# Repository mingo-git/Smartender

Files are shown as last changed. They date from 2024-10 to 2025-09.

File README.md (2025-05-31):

# Smartender

## Deployment

### 1. Image bauen

```bash
docker build -t gcr.io/gothic-sequence-443115-v5/smartender:latest .
```

### 2. Image pushen

```bash
docker push gcr.io/gothic-sequence-443115-v5/smartender:latest
```

### 3. Befehl um das neuste Image zu deployen

```bash
gcloud run services update smartender --image gcr.io/gothic-sequence-443115-v5/smartender:latest --region europe-west3
```

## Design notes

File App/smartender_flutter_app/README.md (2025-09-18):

# smartender_flutter_app

Smartender = Smart Bartender - Flutter

## Getting Started

This project is a starting point for a Flutter application.

A few resources to get you started if this is your first Flutter project:

- [Lab: Write your first Flutter app](https://docs.flutter.dev/get-started/codelab)
- [Cookbook: Useful Flutter samples](https://docs.flutter.dev/cookbook)

For help getting started with Flutter development, view the
[online documentation](https://docs.flutter.dev/), which offers tutorials,
samples, guidance on mobile development, and a full API reference.

In die .env ->
GOOGLE_WEB_CLIENT_ID=*Generate your own Client-ID*
BASE_URL=*Use for Development your ip (Windows -> "ipconfig")*
API_KEY=*???*

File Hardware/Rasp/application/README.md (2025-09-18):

# Suggested File structure according to ChadGPT

```plainText
iot_project/
│
├── main.py                    # Einstiegspunkt der Anwendung
├── config.py                  # Konfigurationsdateien und Parameter
├── modules/                   # Modulverzeichnis
│   ├── websocket_handler.py   # Websocket-Logik
│   ├── motor_controller.py    # Steuerung des Servo- und Linearmotors
│   ├── pump_controller.py     # Pumpensteuerung
│   ├── position_handler.py    # Logik für Endschalter und Positionshandling
│   ├── weight_sensor.py       # Waagenanbindung
│   ├── led_controller.py      # Steuerung des LED-Streifens
│   ├── command_mapper.py      # Befehlsmapper für Websocket-Befehle
│   ├── error_handler.py       # Fehlerbehandlung und Rückmeldungen
│   └── utils/                 # Hilfsfunktionen und Utility-Skripte
│       └── logger.py          # Logging
│
└── tests/                     # Unittests
    ├── test_websocket.py
    ├── test_motors.py
    ├── test_pumps.py
    └── ...
```

## TODOs

- [ ] main.py anlegen und füllen
- [ ] Websocket Klasse implementieren
- [ ] Websocket automatischer reconnect wenn Verbindung unterbrochen wird
- [ ] MotorController Klasse anlegen
- [ ] PumpController Klasse anlegen
- [ ] PositionHandler Klasse anlegen
- [ ] WeightSensor Klasse anlegen
- [ ] LEDController Klasse anlegen
- [x] CommandMapper Klasse anlegen
- [ ] ErrorHandler Klasse anlegen
- [x] Logger Klasse anlegen
- [ ] BashScript für schnelle Installation aller Python Packages

## Pins

| PINS | INFO | USAGE | PINS | INFO | USAGE |
| --- | --- | --- | --- | --- | --- |
| Pin 1  | 3.3 V | | Pin 2  | 5 V | |
| Pin 3  | GPIO 2 | | Pin 3  | 5 V | |
| Pin 5  | GPIO 3 | | Pin 6  | Ground | Ground for Raspberry Pi |
| Pin 7  | GPIO 4 | Limit Switch 1 C | Pin 8  | GPIO 14 | LCD SDA |
| Pin 9  | Ground | | Pin 10 | GPIO 15 | LCD SCL |
| Pin 11 | GPIO 17 | Limit Switch 2 C | Pin 12 | GPIO 18 (PWM) | LED LV1 |
| Pin 13 | GPIO 27 | Limit Switch 3 C | Pin 14 | Ground | Shared Ground |
| Pin 15 | GPIO 22 | Limit Switch 4 C | Pin 16 | GPIO 23 | |
| Pin 17 | 3.3 V | | Pin 18 | GPIO 24 | |
| Pin 19 | GPIO 10 | Limit Switch 5 C | Pin 20 | Ground | |
| Pin 21 | GPIO 9 | Limit Switch 6 C | Pin 22 | GPIO 25 | Linear Actuator IN1 |
| Pin 23 | GPIO 11 | Limit Switch 7 C | Pin 24 | GPIO 8 | Linear Actuator IN2 |
| Pin 25 | Ground | | Pin 26 | GPIO 7 | Linear Actuator IN3 |
| Pin 27 | GPIO 0 | Pump 1 | Pin 28 | GPIO 1 | Linear Actuator IN4 |
| Pin 29 | GPIO 5 | Pump 2 | Pin 30 | Ground | |
| Pin 31 | GPIO 6 | Pump 3 | Pin 32 | GPIO 12 (PWM) | Stepper DA |
| Pin 33 | GPIO 13 (PWM) | Pump 4 | Pin 34 | Ground | Ground Stepper |
| Pin 35 | GPIO 19 (PWM) | Pump 5 | Pin 36 | GPIO 16 | Stepper Dir |
| Pin 37 | GPIO 26 | Pump 6 | Pin 38 | GPIO 20 | Scale DT |
| Pin 39 | Ground | | Pin 40 | GPIO 21 | Scale SCK |

## Liste der nötigen Python-Imports

- `sudo apt install python3-websocket`
- `sudo apt install python3-rx`
- `sudo apt-get install python3-pip`
- `pip install --break-system-packages 'git+https://github.com/gandalf15/HX711.git#egg=HX711&subdirectory=HX711_Python3'`

- `sudo pip3 install XYZ --break-system-packages`

## Pi neu aufsetzen

- sudo apt install git
- ssh-keygen -t ed25519 -C "your_email@example.com"
- git config --global user.email "you@example.com"
- git config --global user.name "Your Name"

- sudo apt install vim
- python3 -m venv ~/myenv
- source ~/myenv/bin/activate
- pip install websocket-client
- pip install rx
- sudo apt update
- sudo apt install python3-dev
- sudo apt install build-essential
- pip install RPi.GPIO
- pip install pigpio
- sudo systemctl enable pigpiod
- sudo systemctl start pigpiod
- pip install hx711
- pip install rpi_ws281x
- pip install python-dotenv
-

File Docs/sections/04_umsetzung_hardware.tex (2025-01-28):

\subsection{Überblick}
Die Hardwareplattform für das Projekt bildet das Herzstück des Cocktailautomaten und wurde mit dem 
Ziel ausgewählt, eine robuste und flexible Steuerung der mechanischen und elektronischen 
Komponenten zu gewährleisten. Die Wahl fiel auf den \textbf{Raspberry Pi Zero 2 W}, eine kompakte 
und leistungsfähige Single-Board-Computer-Lösung, die sich aufgrund ihrer Vielseitigkeit und der 
umfangreichen Unterstützung von Python-Bibliotheken ideal für IoT-Anwendungen eignet. Ergänzt wird 
der Raspberry Pi durch eine Vielzahl von Sensoren, Aktoren und Peripheriegeräten, die zusammen die 
präzise Steuerung des Automaten ermöglichen.

\subsection{Zentrale Steuerung}
\hyphenation{Blue-tooth-Kon-nek-ti-vi-tät}
\hyphenation{WLAN-Kon-fi-gu-ra-tion}
% TODO: fix hyphenation for 'Bluetooth-Konnektivität'
Der Raspberry Pi Zero 2 W übernimmt die zentrale Steuerung des Systems. Mit einem Quad-Core ARM 
Cortex-A53-Prozessor und integrierter WLAN- und Bluetooth-Konnektivität \cite{raspberrypi} eignet 
sich der Pi optimal für die Verarbeitung der Steuerungslogik und die Kommunikation mit dem Backend.

\subsection{Mechanische Komponenten}
\subsubsection{Schrittmotor für die Positionierung}
Ein Schrittmotor steuert die präzise Bewegung eines Förderbandsystems, welches die verschiedenen 
Getränkezutaten anfahren kann. Mit einem Dir- und Pul-Pin-Design wird der Schrittmotor über einen 
\textbf{Treiber} angesteuert, der eine feine Steuerung der Bewegung und Geschwindigkeit ermöglicht. 
Ein Schlitten bewegt sich zwischen den Slots, die durch Endschalter (Limit Switches) abgegrenzt 
sind.

\subsubsection{Linearantrieb für alkoholische Getränke}
Ein Linearmotor aktiviert die Dosiermechanismen für alkoholische Zutaten, die kopfüber montiert 
sind. Der Antrieb hebt die Dosiermechanik an, um Flüssigkeiten aus den Flaschen freizugeben, und 
stellt sicher, dass die gewünschte Menge präzise abgefüllt wird.

\subsubsection{Membranpumpen für nicht-alkoholische Zutaten}
Sechs Membranpumpen sind für die Abgabe von nicht-alkoholischen Zutaten zuständig. Diese Pumpen 
ermöglichen eine genaue Dosierung der Flüssigkeiten und werden einzeln über GPIO-Pins des 
Raspberry Pi angesteuert. Jede Pumpe ist einem festen Slot zugewiesen.

\subsection{Sensorik}
\subsubsection{Endschalter für die Positionserkennung}
Sechs Endschalter (Limit Switches) überwachen die genaue Position des Schlittenmechanismus. 
Endschalter 0 ist für die Kalibrierung vorgesehen und dient als Referenzpunkt. Außerdem werden an 
diesem Punkt die nicht-alkoholischen Getränke am Ende der Zubereitung zugefügt. Die übrigen 
Schalter (1--5) bilden die Position der Slots für alkoholische Getränke (ebenfalls 1--5) ab.

\subsubsection{Waage für Gewichtsmessung}
Eine elektronische Waage auf Basis eines HX711-Sensors misst das Gewicht der Getränke während der 
Zubereitung. Sie dient nicht nur der Überwachung der genauen Flüssigkeitsmengen, sondern auch der 
Erkennung, ob eine Zutat aufgebraucht ist.

\subsection{Stromversorgung}
Die gesamte Hardware wird von einem \textbf{24V-Netzteil} mit ausreichender Leistung (mindestens 3A
) versorgt. Zwei \textbf{Step-Down-Spannungsregler} wandeln die Spannung auf 5V respektive 12V für 
den Raspberry Pi und weitere elektronische Komponenten um. Zur Vermeidung von 
Spannungsschwankungen und elektromagnetischen Störungen wurden \textbf{Kondensatoren} integriert, 
die die Stabilität der Stromversorgung sicherstellen.

\subsection{Zusammenarbeit der Komponenten}
Alle Hardwarekomponenten arbeiten nahtlos zusammen, um die Zubereitung eines Cocktails zu 
automatisieren:
\begin{itemize}
    \item Die \textbf{Positionserkennung} sorgt dafür, dass der Schlitten immer die korrekte 
        Position ansteuert.
    \item Die \textbf{Waage} und die Pumpen oder der Linearantrieb arbeiten zusammen, um die 
        exakte Menge jeder Zutat abzugeben.
\end{itemize}

\subsection{Pinbelegung und Schaltplan}
Die genaue Pinbelegung \ref{fig:pinning} sowie der vollständige Schaltplan \ref{fig:schaltplan} 
der Hardware sind im Anhang zu finden. Das Pinning-Sheet dokumentiert die Zuordnung der GPIO-Pins 
des Raspberry Pi zu den verschiedenen Komponenten wie Schrittmotor, Linearantrieb, Pumpen, 
Endschaltern und Waage. Der Schaltplan bietet einen Überblick über die elektrische Verkabelung und 
die Integration der Stromversorgung sowie der Steuereinheiten. Beide Dokumente sind essenziell für 
den Nachbau oder die Wartung des Systems.

\subsection{Integration und Herausforderungen}
% TODO: fix hyphenation to fix overfull hbox in 'Stromversorgung'
Die Integration der verschiedenen Hardwarekomponenten erforderte eine sorgfältige Planung, 
insbesondere bei der Belegung der GPIO-Pins und der Kalibrierung der Sensoren. Eine besondere 
Herausforderung stellte die Stabilität der Stromversorgung dar, insbesondere bei Spitzenlasten 
durch den Schrittmotor oder die Pumpen. Durch die Verwendung eines ausreichend dimensionierten 
Netzteils und der Optimierung des Codes konnte dieses Problem erfolgreich gelöst werden.

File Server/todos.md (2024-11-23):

Todos for Server/Database

- [] Endpunkt: Getärnk zubereiten
- [] SQL Query für Rezeptzubereitung (Slots, welcher SLot wie viel usw.)
- [] Datenbankschema migrieren (User, Google Token usw.)
- [] Endpoint Hardware registrieren (User ID)
- [] Mapping Rezepte Backend mit SQL Statement
- [] Rezept über Socket an Pi

- Testing! (Ob Rezepte auf Pi ankommen)

Todos for Pi

- [] Eigenes Wlan aufbauen für Ersteinrichtung
- [] Ersteinrichtung (HW im Backend registrieren etc.)
- [] Datenbankrezepte mappen auf "Arduino Befehle"
- [] Verbindung zu Arduino über I2C/UART (nochmal informieren)
- [] "Arduino Befehle" definieren

- Testing! (Ob Befehle bei Arduino ankommen)

Todos for Arduino

- [] Errorcodes für Fehlerfälle
- [] Daten von Pi auslesen/casten
- [] Großes Switch Statement
- [] Funktionen für Move/Pump/Push
- [] Pins ansteuern

- Testing! (Mit LEDs, einzelne Ports ansprechen)

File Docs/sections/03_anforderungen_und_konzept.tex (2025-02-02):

% Hier folgt der Inhalt des Abschnitts "Anforderungen und Konzept".
Im Rahmen des Projekts „Smarter Cocktailautomat“ wurden grundlegende Anforderungen definiert, die 
sich aus den Zielsetzungen und den zu erwartenden Einsatzszenarien ableiten lassen. Dieser 
Abschnitt gliedert sich in eine Analyse der funktionalen und nicht-funktionalen Anforderungen 
sowie die Entwicklung eines konzeptionellen Architekturansatzes, der die Interaktionen zwischen 
Hardware, Backend und mobiler App beschreibt.

\subsection{Anforderungsanalyse}

Die Anforderungsanalyse bildet die Grundlage für die Entwicklung des Prototyps. Dabei werden 
sowohl funktionale als auch nicht-funktionale Anforderungen betrachtet.

\subsection{Funktionale Anforderungen}

Funktionale Anforderungen beschreiben die Kernfunktionen, die das System erfüllen muss, um die 
Projektziele zu erreichen:

\begin{itemize}
	  \item \textbf{Benutzerregistrierung:} Möglichkeit, Benutzerkonten anzulegen.
	  \item \textbf{Rezeptverwaltung:} Hinzufügen, Bearbeiten und Löschen von Cocktailrezepten über die mobile App.
	  \item \textbf{Zutatenverwaltung:} Verwaltung der im Automaten verfügbaren Zutaten.
	  \item \textbf{Automatisierte Zubereitung:} Präzise Dosierung und Mischung der ausgewählten Zutaten basierend auf den Rezepten.
	  \item \textbf{App-Steuerung:} Steuerung des Cocktailautomaten über eine intuitive Benutzeroberfläche der mobilen App.
	  \item \textbf{Synchronisation mit der Cloud:} Speicherung und Abruf von Benutzerdaten, Rezepten und Maschinenkonfigurationen über ein cloudbasiertes Backend.
\end{itemize}

\subsection{Nicht-funktionale Anforderungen}

Neben den funktionalen Aspekten spielen auch nicht-funktionale Anforderungen eine zentrale Rolle, 
um die Qualität und Benutzerfreundlichkeit des Systems sicherzustellen:

\begin{itemize}
	  \item	\textbf{Skalierbarkeit:} Das System muss in der Lage sein, mehrere Benutzer zu unterstützen, ohne Leistungseinbußen zu erleiden.
	  \item	\textbf{Sicherheitsaspekte:} Schutz von Benutzerdaten durch verschlüsselte Kommunikation und sichere Authentifizierungsverfahren.
	  \item	\textbf{Benutzerfreundlichkeit:} Intuitive Bedienung der mobilen App sowie einfache Wartung und Erweiterung der Hardware.
	  \item	\textbf{Fehlerresistenz:} Robustheit des Systems gegenüber Hardware- und Softwarefehlern.
	  \item	\textbf{Performance:} Minimierung von Latenzen bei der Kommunikation zwischen App, Backend und Hardware.
\end{itemize}

\subsection{Konzeptionelle Architektur}

Auf Basis der definierten Anforderungen wurde eine konzeptionelle Architektur entwickelt, die das 
Gesamtsystem in seinen zentralen Komponenten beschreibt.

Gesamtsystem-Übersicht

Das System besteht aus drei Kernkomponenten:

\begin{enumerate}
  \item \textbf{Hardware:} Der Cocktailautomat als physisches Gerät übernimmt die Dosierung und Mischung der Zutaten.
  \item \textbf{Backend:} Ein containerisiertes Backend, das in Google Cloud Run gehostet wird, dient als zentrale Schnittstelle für die Speicherung und Verarbeitung von Daten.
  \item \textbf{Mobile App:} Eine Smartphone-App ermöglicht die Benutzerinteraktion mit dem System und bietet Funktionen wie Rezeptverwaltung und Steuerung des Automaten.
\end{enumerate}

Die Interaktionen zwischen diesen Komponenten sind in Abbildung \ref{fig:system_overview} 
dargestellt. Dabei wird insbesondere der Datenfluss zwischen den Modulen hervorgehoben.

\vspace{0.5 cm}
\begin{figure}[htbp]
  \centering
	\begin{tikzpicture}[
		>=stealth,   					% Standardpfeilspitzen
		outer sep=6pt,				% Abstand zwischen Text und Rahmen
		inner sep=5pt,				% Abstand zwischen Text und Rahmen
		node distance=6cm,	% Abstand zwischen den Knoten
		font=\sffamily				% Verwendete Schriftart
	]
	
	% Knoten
	\node[draw, rectangle, rounded corners, fill=red3, minimum width=2.5cm, minimum height=1.2cm] (hardware) {Hardware};
	\node[draw, rectangle, rounded corners, fill=red3, minimum width=2.5cm, minimum height=1.2cm, left of=hardware] (backend) {Backend};
	\node[draw, rectangle, rounded corners, fill=red3, minimum width=2.5cm, minimum height=1.2cm, left of=backend] (app) {Mobile App};
	
	% Pfeil 1: ein Wort pro Zeile, zentriert
	\draw[<-, thick] 
	(hardware) 
	-- node[below]{
		\parbox{2.7cm}{\centering
			Rezeptdaten,\\
			Slotbestückung 
		}
	} 
	(backend);

	% Pfeil 2: ein Wort pro Zeile, zentriert
	\draw[<->, thick] 
	(app) 
	-- node[below]{
		\parbox{2.7cm}{\centering
			Benutzerdaten,\\
			Rezepte \&\\
			Konfiguration
		}
	} 
	(backend);

	\end{tikzpicture}

	\caption{Systemübersicht: Interaktionen zwischen Hardware, Backend und mobiler App}
	\label{fig:system_overview}
\end{figure}

\paragraph*{Datenflüsse und Interaktionen}

\begin{itemize}
  \item Die Hardware kommuniziert mit dem Backend, um die aktuellen Maschinenzustände zu synchronisieren.
  \item Die mobile App greift auf das Backend zu, um Benutzerdaten, Rezepte und Maschinenkonfigurationen zu laden und zu speichern.
  \item Das Backend dient als zentrale Vermittlungsstelle und verarbeitet sowohl Steuerbefehle von der App als auch Statusmeldungen der Hardware.
\end{itemize}

\subsection{Schwerpunktsetzung}

Im Rahmen des Projekts wurde besonderes Augenmerk auf die folgenden Aspekte gelegt:

\begin{itemize}
  \item \textbf{Hardware:} Die Hardwareentwicklung zielte auf eine modulare und erweiterbare Bauweise ab, um zukünftige Anpassungen und Erweiterungen zu ermöglichen.
  \item \textbf{Backend:} Aufgrund der hohen Anforderungen an Skalierbarkeit und Sicherheit wurde das Backend so konzipiert, dass es sowohl eine zuverlässige Kommunikation zwischen den Komponenten als auch eine effiziente Datenverwaltung ermöglicht.
  \item \textbf{Mobile App:} Der Fokus lag auf einer benutzerfreundlichen und intuitiven Bedienung, um die Nutzung auch für technisch unerfahrene Anwender zu vereinfachen.
\end{itemize}

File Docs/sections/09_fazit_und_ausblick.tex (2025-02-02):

% Hier folgt der Inhalt des Abschnitts "Fazit und Ausblick".
\subsection{Fazit}
Das Projekt hat gezeigt, dass die Kombination aus Hardware, Software und Cloud-Diensten 
erfolgreich zur Automatisierung der Cocktailzubereitung genutzt werden kann. Die definierten 
Hauptziele des Projekts wurden weitestgehend erreicht:

\begin{itemize}
    \item Die Maschine kann Cocktails entsprechend der über die App ausgewählten Rezepte 
        zusammenmixen.
    \item In der App können Benutzer Getränke, Zutaten und Slots anlegen, ändern und löschen.
    \item Die Integration zwischen App, Backend und Hardware funktioniert stabil und erfüllt die 
        Kernanforderungen.
\end{itemize}

Besonders positiv hervorzuheben ist die erfolgreiche Umsetzung folgender Punkte:

\begin{itemize}
    \item Hosting des Backends über Google Cloud
    \item Erstellung einer funktionsfähigen Android-App
    \item Zuverlässige Verkabelung und Integration der Hardware
\end{itemize}
Trotz der Erfolge gab es auch Herausforderungen, die nur teilweise gelöst werden konnten. 
Beispielsweise verursachen die Treiber des Schrittmotors und des Linearmotors Schwankungen im 
Ground, was die Übertragung von Daten beeinträchtigt. Dies führt insbesondere bei feineren 
Komponenten wie der Waage zu Störungen, obwohl diese außerhalb des Systems problemlos funktioniert 
hat.

Zudem gab es Einschränkungen bei der Auswahl bestimmter Hardware-Komponenten. So sind die 
Spirituosenausschänker gelegentlich unzuverlässig, was zu Ausfällen führen kann. Die Kraft, die 
erforderlich ist, um diese Ausschänker zu bedienen, wurde ebenfalls unterschätzt. Dies machte 
einen Wechsel von Servomotoren zu einem leistungsfähigeren Linearmotor notwendig.

Insgesamt hat das Projekt die Kenntnisse im Bereich Elektronik, Stromversorgung sowie in der 
Entwicklung und Bereitstellung von Apps und Backends erheblich erweitert.

\subsection{Ausblick}
Für die Zukunft sind mehrere Erweiterungen und Optimierungen geplant, um die Funktionalität und 
Zuverlässigkeit des Systems weiter zu verbessern:

\begin{itemize}
    \item \textbf{Ansteuerbare LEDs:} Diese sollen nicht nur für eine ansprechende Optik sorgen, sondern
    auch leere Flaschen in den Slots durch die gezielte Ansteuerung einzelner LEDs sichtbar machen. Die Umsetzung wird jedoch durch Störsignale im Ground beeinträchtigt, die zunächst behoben werden müssen.
    \item \textbf{Rollenzuweisung:} Benutzer sollen unterschiedliche Rollen erhalten, um 
        beispielsweise das Verändern von Rezepten und Zutaten auf autorisierte Nutzer zu beschränken.
    \item \textbf{Hardwareverwaltung in der App:} Es soll möglich sein, mehrere Smartender-Geräte 
        über die App zu steuern und zu verwalten.
    \item \textbf{Spülprogramm:} Ein automatisches Spülprogramm soll die Reinigung der Schläuche 
        erleichtern und Restflüssigkeiten entfernen.
    \item \textbf{WLAN-Einrichtung:} Die WLAN-Konfiguration soll über die App erfolgen, um die 
        Notwendigkeit einer Tastatur und eines Displays am Raspberry Pi zu vermeiden und die 
        Einrichtung zu erleichtern.
    \item \textbf{Integration einer Waage:} Eine Waage soll die genaue Bestimmung der im Becher 
        befindlichen Flüssigkeitsmenge ermöglichen. Dies erfordert jedoch die Behebung der 
        bestehenden Störsignale im Ground.
\end{itemize}
Diese Erweiterungen würden den Smartender zu einer noch vielseitigeren Lösung für private und 
kommerzielle Anwendungen machen.

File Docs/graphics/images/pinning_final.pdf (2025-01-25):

Pin 1 | 3.3 V | | Pin 2 | 5 V | Power Pi
Pin 3 | GPIO 2 | | Pin 4 | 5V
Pin 5 | GPIO 3 | | Pin 6 | Ground | Ground Pi
Pin 7 | GPIO 4 | Limit Switch 0 C | Pin 8 | GPIO 14 | LCD SDA
Pin 9 | Ground | | Pin 10 | GPIO 15 | LCD SCL
Pin 11 | GPIO 17 | Limit Switch 1 C | Pin 12 | GPIO 18 (PWM) | LEDs LV1
Pin 13 | GPIO 27 | Limit Switch 2 C | Pin 14 | Ground | Ground Shared
Pin 15 | GPIO 22 | Limit Switch 3 C | Pin 16 | GPIO 23
Pin 17 | 3.3 V | | Pin 18 | GPIO 24
Pin 19 | GPIO 10 | Limit Switch 4 C | Pin 20 | Ground
Pin 21 | GPIO 09 | Limit Switch 5 C | Pin 22 | GPIO 25
Pin 23 | GPIO 11 | | Pin 24 | GPIO 8
Pin 25 | Ground | | Pin 26 | GPIO 7 | Linear Actuator IN3
Pin 27 | GPIO 0 | Pump 1 | Pin 28 | GPIO 1 | Linear Actuator IN4
Pin 29 | GPIO 5 | Pump 2 | Pin 30 | Ground | Ground Pull
Pin 31 | GPIO 6 | Pump 3 | Pin 32 | GPIO 12 (PWM) | Stepper Pull
Pin 33 | GPIO 13 (PWM) | Pump 4 | Pin 34 | Ground | Ground DIR
Pin 35 | GPIO 19 (PWM) | Pump 5 | Pin 36 | GPIO 16 | Stepper DIR
Pin 37 | GPIO 26 | Pump 6 | Pin 38 | GPIO 20 | Scale DT
Pin 39 | Ground | | Pin 40 | GPIO 21 | Scale SCK

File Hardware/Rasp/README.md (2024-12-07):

# Flask Webserver

Ein einfacher Flask-Webserver als Grundlage für weitere Entwicklungen.

## Einrichtung

1. **Virtuelle Umgebung erstellen**:
```bash
   python -m venv .venv
```

2.	**Virtuelle Umgebung aktivieren**:
```bash
source .venv/bin/activate
```

3.	**Abhängigkeiten installieren**:
```bash
pip install flask
```

4.	**Interpreter in VSCode setzen**:
	•	Öffne die Befehlspalette (Strg+Shift+P).
	•	Wähle Python: Select Interpreter und dann .venv.

## Server starten

Aktiviere die virtuelle Umgebung und starte den Server:

```bash
python app.py
```

Öffne [link](http://127.0.0.1:5000) im Browser.

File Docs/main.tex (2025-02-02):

\documentclass[a4paper, 10pt]{article} % A4-Seitenformat und Schriftgröße 12pt

% Pakete für Sprache, Schrift und andere wichtige Anpassungen
\usepackage[utf8]{inputenc} % UTF-8 Unterstützung für Umlaute (ä, ü, ö)
\usepackage[T1]{fontenc}    % Korrekte Silbentrennung bei Umlauten
\usepackage[ngerman]{babel} % Deutsche Spracheinstellungen (z. B. Texttrennung, Typografie)
\usepackage{csquotes}       % Korrekte deutsche Anführungszeichen („ “)
\usepackage{hyperref} 		  % Klickbare Links im PDF
\hypersetup{
  colorlinks = false,       % Keine farbigen Links
  pdfborder  = {0 0 0}      % Kein Rahmen um Links
}
\usepackage{geometry}       % Seitenränder anpassen
\usepackage{float}					% Positionierung von Bildern und Tabellen

\usepackage{listings}			  % Code-Listings

\usepackage{tikz}           % Grafiken und Diagramme
% \tikzexternalize 					% Externe Speicherung von TikZ-Grafiken (schnelleres Kompilieren)
\usetikzlibrary{shadings}
\usetikzlibrary{calc,arrows.meta}

\usepackage{pgfplots}			  % Diagramme und Plots
\usepgfplotslibrary{external} % Externe Speicherung von Plots (schnelleres Kompilieren)
\usepgfplotslibrary{statistics}
\pgfplotsset{width=\textwidth,compat=1.18}

\usepackage{fullpage} 		 	% Seitenränder auf 1 Zoll setzen
\usepackage{ulem} 				 	% Unterstreichungen und Durchstreichungen
\usepackage{xcolor}

\usepackage{amssymb,amsmath,changepage,tabularx,siunitx} % Mathematische Symbole und Umgebungen
% \usepackage{darkmode}
% \enabledarkmode 					% Dunkler Modus für bessere Lesbarkeit
\usepackage{makecell} 			% Tabellenzellen formatieren
\usepackage{bookmark} 			% Lesezeichen im PDF

\usepackage{titlesec}
% Syntax: \titlespacing*{\section}{left}{before}{after}
% - left  = linker Einzug
% - before = Abstand vor der Überschrift
% - after  = Abstand nach der Überschrift
\titlespacing*{\section}{0pt}{0.8\baselineskip}{0.6\baselineskip}
\titlespacing*{\subsection}{0pt}{0.6\baselineskip}{0.4\baselineskip}
\titlespacing*{\subsubsection}{0pt}{\baselineskip}{0.4\baselineskip}

\usepackage{enumitem}
\setlist[itemize]{itemsep=0.3em, topsep=0.4em}
\setlist[enumerate]{itemsep=0.3em, topsep=0.4em}

\usepackage[most]{tcolorbox}
\definecolor{red1}{HTML}{ffccd5}
\definecolor{red2}{HTML}{ffb3c1}
\definecolor{red3}{HTML}{ff8fa3}
\definecolor{red4}{HTML}{ff758f}
\definecolor{red5}{HTML}{ff4d6d}
\definecolor{red6}{HTML}{c9184a}
\definecolor{red7}{HTML}{a4133c}
\definecolor{red8}{HTML}{800f2f}
\definecolor{red9}{HTML}{590d22} 
\definecolor{red10}{HTML}{c9181e}
\definecolor{red11}{HTML}{c91876}
\definecolor{red12}{HTML}{e5235a}
\definecolor{pag}{HTML}{293133}
	\usepgfplotslibrary{colormaps,patchplots}
\definecolor{cbada55}{RGB}{186,218,85}
\definecolor{c2c2c2c}{RGB}{44,44,44}
\definecolor{cc9184a}{RGB}{201,24,74}
\definecolor{c8d354e}{RGB}{141,53,78}
\definecolor{cff4d6d}{RGB}{255,77,109}
\definecolor{cff758f}{RGB}{255,117,143}
		\usetikzlibrary{3d,perspective}

\newtcolorbox{qq}[2][]{  
	boxrule=0.75pt, % Thin border
	sharp corners, 	% Square edges
	colframe=white, % Set the color of the outline
	colback=pag,  	% Set the color of the fill
	coltext=white,	% Set the color of the text
	#1,							% Other options
}

\lstset{
  basicstyle=\ttfamily,
  keywordstyle=\bfseries\color{red3},
  commentstyle=\itshape\color{red12},
  stringstyle=\color{red5},
  numbers=left,
  numberstyle=\small,
  stepnumber=1,
  breaklines=true,
	frame=single,
	captionpos=b,
	xleftmargin=0.1cm,
	xrightmargin=0.1cm,	
}

% JavaScript definieren
\lstdefinelanguage{JavaScript}{
    keywords={break,case,catch,class,const,continue,debugger,default,delete,do,
      else,export,extends,finally,for,function,if,import,in,instanceof,let,new,
      return,super,switch,this,throw,try,typeof,var,void,while,with,yield, from},
    sensitive=true,
    morecomment=[l]{//},
    morecomment=[s]{/*}{*/},
    morestring=[b]",
    morestring=[b]'
}

% Python definieren
\lstdefinelanguage{Python}{
	keywords={},
	sensitive=true,
	morecomment=[l]{\#},
	morestring=[b]',
	morestring=[b]",
}

\usepackage{mathpazo} % Palatino Schriftart

\usetikzlibrary{decorations.markings,arrows.meta,bending}
\usepackage{tikz-3dplot}
\usetikzlibrary{3d,backgrounds,intersections}

\makeatletter
\tikzoption{canvas is xy plane at z}[]{%
	\def\tikz@plane@origin{\pgfpointxyz{0}{0}{#1}}%
	\def\tikz@plane@x{\pgfpointxyz{1}{0}{#1}}%
	\def\tikz@plane@y{\pgfpointxyz{0}{1}{#1}}%
	\tikz@canvas@is@plane}
\makeatother

\usepgfplotslibrary{groupplots}
\usepgfplotslibrary{fillbetween}

\usepackage{colortbl}
\usepackage{caption}
\usepackage{polynom}
\usepackage[backend=biber, sorting=none, style=numeric]{biblatex}
\addbibresource{literaturverzeichnis.bib}

% \usepackage[top=1in,bottom=1in,right=1in,left=1in]{geometry}
% \usepackage{mdframed}
\usepackage{array}
\usepackage{multirow}
\definecolor{pagtwo}{HTML}{3E4547}

\geometry{a4paper, left=3cm, right=3cm, top=2.5cm, bottom=2.5cm} % Beispiel für Seitenränder

\begin{document}

\begin{titlepage}
	% Logo oben links
    \begin{flushleft}
		\vspace*{-1.5cm}            % nach oben verschieben
		\hspace*{-1.0cm}           % nach links verschieben
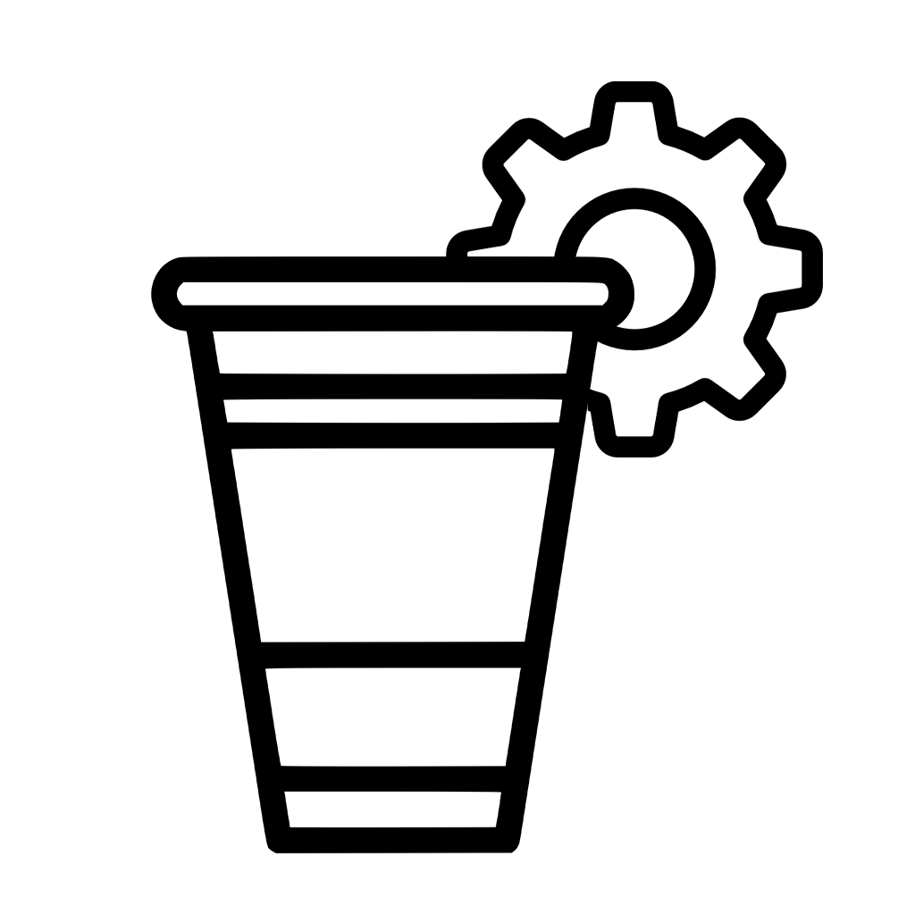
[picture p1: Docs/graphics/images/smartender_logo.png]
         % Pfad+Name Ihrer Bilddatei, z.B. "logo.png"
    \end{flushleft}

    % Evtl. ein kleiner negativer Vertikalabstand, 
    % wenn das Titelzentrum weiter oben liegen soll:
    \vspace*{-1.5cm}
	\centering
	\vspace*{1cm}
	{\Huge \bfseries Automatisierter Smarter Cocktail-Automat mit Cloud Anbindung\par}
  
	\vspace{2cm}
	{\large
	  \textbf{Jonas Eck}\\
	  Technische Hochschule Würzburg-Schweinfurt\\[1em]
	  \textbf{Philipp Schön}\\
	  Technische Hochschule Würzburg-Schweinfurt\\[1em]
	  \textbf{Constantin Thein}\\
	  Technische Hochschule Würzburg-Schweinfurt
	}
  
	\vspace{2cm}
	{\large \today\par}
  
	\vspace{2cm}
	\begin{abstract}
		\normalsize
		Im Rahmen dieses Projekts wurde ein smarter Cocktailautomat entwickelt, der wesentliche Elemente des Internet of Things (IoT) mit den Anforderungen moderner Smart-Home-Lösungen verbindet. Ziel war die Umsetzung eines skalierbaren Prototyps, der die automatisierte Zubereitung von
		Cocktails ermöglicht und dabei durch eine intuitive Bedienung über eine Smartphone-App sowie die Anbindung an ein cloudbasiertes Backend besticht.
	
		Die Lösung umfasst drei Kernkomponenten: eine modular aufgebaute
		Hardware für die Cocktailzubereitung, ein containerisiertes Backend gehostet in Google Cloud Run mit einer Cloud-SQL-Datenbank, sowie eine mobile App, die eine benutzerfreundliche Verwaltung von Rezepten, Zutaten
		und Maschinenkonfigurationen erlaubt. Besonderes Augenmerk wurde auf
		die Skalierbarkeit und Erweiterbarkeit des Systems gelegt.
	
		Das Projekt zeigt die Potenziale von IoT-Technologien auf, alltägliche Aufgaben zu automatisieren und dabei innovative Ansätze für Smart-Home-Umgebungen zu entwickeln. Gleichzeitig wurden Herausforderungen wie
		die Einarbeitung in neue Technologien, der Umgang mit komplexen Elektronikkomponenten sowie die effiziente Integration von Cloud-Diensten gemeistert.
	\end{abstract}
  
	\vfill
  \end{titlepage}

\newpage

\section{Einleitung}
\input{sections/01_einleitung}    
% \newpage

\section{Technologischer Hintergrund und Grundlagen}
\input{sections/02_technologischer_hintergrund}    
% \newpage

\section{Anforderungen und Konzept}
\input{sections/03_anforderungen_und_konzept}    
% \newpage

\section{Umsetzung der Hardware}
\input{sections/04_umsetzung_hardware}    
% \newpage

\section{Backend-Architektur und Implementierung}
\input{sections/05_backend_architektur_und_implementierung}    
% \newpage

\section{Mobile App-Entwicklung}
\input{sections/06_mobile_app_entwicklung}    
% \newpage

\section{Integration und Tests}
\input{sections/07_integration_und_tests}    
% \newpage

\section{Ergebnisse und Bewertung}
\input{sections/08_ergebnisse_und_bewertung}
% \newpage

\section{Fazit und Ausblick}
\input{sections/09_fazit_und_ausblick}    
\newpage

\section{Anhang}
\input{sections/10_anhang}    
\newpage

\printbibliography[heading=bibintoc, title={Literaturverzeichnis}, notcategory=ignore]
\listoffigures
\listoftables
% \newpage

\end{document}

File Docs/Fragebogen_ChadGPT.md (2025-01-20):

# First Draft

1. Vorbereitung und Ersteindruck

- Fragen vor der Nutzung:
- Haben Sie Erfahrung mit ähnlichen Apps? Wenn ja, welche?
- Was erwarten Sie von einer App, die Rezepte und Getränke verwaltet?
- Wie intuitiv wirkt die Startoberfläche der App auf den ersten Blick?

2. Aufgabenorientierte Fragen

- Fragen während der Nutzung (Beobachtung der Nutzer):
- Wie lange haben Sie gebraucht, um ein Rezept zu erstellen? (Zeit messen)
- Hatten Sie Probleme, die benötigten Funktionen für die Rezept-Erstellung zu finden? Wenn ja, welche?
- Waren alle Buttons, Menüs und Texte klar und verständlich?
- Wie schwierig war es, Zutaten zu einem Rezept hinzuzufügen? (Skala 1–5: Sehr leicht bis Sehr schwer)
- Haben Sie versehentlich Aktionen ausgeführt (z. B. ein Rezept gelöscht oder geändert)?
- Haben Sie die Favoriten-Funktion genutzt? Falls nein, warum nicht?

3. Feedback zu Design und Navigation

- Subjektives Feedback:
- Wie bewerten Sie das Layout der App? (Skala 1–5: Unübersichtlich bis Sehr übersichtlich)
- Waren die Farben und Schriften angenehm zu lesen und optisch ansprechend?
- Gab es Funktionen, die schwer zu finden oder unklar waren? Welche?
- Was halten Sie von der Geschwindigkeit der App bei der Navigation und Datenaktualisierung?

4. Gesamtbewertung und Verbesserungsvorschläge

- Nach der Nutzung:
- Wie intuitiv empfanden Sie die Bedienung der App insgesamt? (Skala 1–5)
- Welche Funktion war besonders einfach zu nutzen? Warum?
- Welche Funktion war besonders schwierig zu nutzen? Warum?
- Haben Sie Vorschläge zur Verbesserung der App? (z. B. fehlende Funktionen, bessere Erklärungen)
- Würden Sie die App anderen empfehlen? Warum oder warum nicht?

5. Spezifische Problemfälle

Falls die Testpersonen auf Probleme stoßen, stellen Sie gezielte Nachfragen:

- Was hat Sie bei dieser Aktion verwirrt?
- Welche Information hätte Ihnen geholfen, dieses Problem zu vermeiden?
- War die Fehlermeldung (falls vorhanden) hilfreich? Warum oder warum nicht?

6. Abschlussfragen

- Hatten Sie Spaß bei der Nutzung der App?
- Fühlen Sie sich nach dem Test in der Lage, die App eigenständig zu bedienen?
- Würden Sie die App regelmäßig nutzen, wenn Sie Bedarf an einem solchen Service hätten?

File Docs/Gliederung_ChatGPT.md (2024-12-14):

Vorschlag für die Struktur der Projektarbeit

1. Einleitung (2–3 Seiten)

 • Projektkontext und Motivation: Warum ein Cocktail-Automat? Bezug zu Smart-Home und IoT-Trends.
 • Ziele des Projekts: Was wird konkret erreicht (z.B. Automatisierung, Benutzerfreundlichkeit, technische Herausforderungen)?
 • Wissenschaftliche Relevanz: Bezug zu aktuellen Entwicklungen in IoT und Cloud-Technologien.
 • Struktur der Arbeit: Kurzer Überblick über die Kapitel.

2. Technologischer Hintergrund und verwandte Arbeiten (3–5 Seiten)

 • IoT und Smart-Home-Systeme: Einleitung zu IoT, Bedeutung im Kontext von Smart-Home-Lösungen.
 • Verwendete Technologien:
 • Raspberry Pi für Hardware-Steuerung.
 • Google Cloud Run und Cloud SQL für das Backend.
 • Smartphone-App und Frameworks.
 • Abgrenzung und Vergleich: Kurzer Vergleich mit bestehenden Lösungen (z.B. kommerzielle Cocktail-Automaten oder IoT-Plattformen).

3. Anforderungen und Konzept (4–5 Seiten)

 • Anforderungsanalyse:
 • Funktionale Anforderungen (z.B. Benutzerregistrierung, Cocktail-Rezepte verwalten, App-Steuerung).
 • Nicht-funktionale Anforderungen (z.B. Skalierbarkeit, Sicherheitsaspekte, Benutzerfreundlichkeit).
 • Konzeptionelle Architektur:
 • Gesamtsystem-Übersicht: Wie arbeiten Hardware, Backend und App zusammen? (mit Diagramm)
 • Darstellung der Datenflüsse und Interaktionen zwischen den Komponenten.
 • Schwerpunktsetzung: Begründung, welche Aspekte (z.B. Hardware, Backend, App) besondere Aufmerksamkeit erhalten.

4. Umsetzung der Hardware (4–6 Seiten)

 • Mechanisches Design:
 • 3D-gedruckte Bauteile, Konstruktion des Automaten, Auswahl der Materialien.
 • Herausforderungen beim Aufbau und Lösungen (z.B. Stabilität, Platz für Pumpen).
 • Elektronik und Steuerung:
 • Verwendete Komponenten: Pumpen, Sensoren, Verkabelung.
 • Schaltplan und Steuerlogik (mit Diagramm).
 • Software auf dem Raspberry Pi:
 • Funktionen und Abläufe (z.B. Pumpensteuerung, Kommunikation mit dem Backend).
 • Technische Details des Codes (z.B. verwendete Bibliotheken).

5. Backend-Architektur und Implementierung (4–6 Seiten)

 • Containerisierung und Cloud-Bereitstellung:
 • Warum Google Cloud Run? Vorteile der Containerisierung.
 • Aufbau der Umgebung und Deployment-Prozesse.
 • Datenbankdesign:
 • Struktur der Cloud SQL-Datenbank (Diagramm mit Tabellen und Relationen).
 • Datenmodelle für Benutzer, Rezepte, Zutaten.
 • API-Schnittstellen:
 • REST-Endpoints: Beschreibung und Beispiele (z.B. POST für Cocktail-Erstellung).
 • Sicherheitsmaßnahmen (z.B. OAuth, Token-Authentifizierung).
 • Besondere Herausforderungen und Lösungen: Skalierbarkeit, Latenz oder Sicherheitsprobleme.

6. Mobile App-Entwicklung (4–5 Seiten)

 • Features der App:
 • Funktionen wie Registrierung, Rezeptverwaltung, Hardware-Steuerung.
 • Auswahl der Plattform (z.B. Android, iOS oder plattformübergreifend).
 • UI/UX-Design:
 • Mockups oder Screenshots zur Visualisierung des Designs.
 • Fokus auf Benutzerfreundlichkeit.
 • Kommunikation mit Backend:
 • Technische Details zur API-Integration (z.B. JSON-Parsing).
 • Technologien und Frameworks:
 • Begründung der Auswahl (z.B. Flutter, Swift, Kotlin).

7. Integration und Tests (4–5 Seiten)

 • Integration der Komponenten:
 • Wie arbeiten Hardware, Backend und App zusammen? (Integrationstests)
 • Technische Details zur Synchronisation der Komponenten.
 • Teststrategie:
 • Unit-Tests, Integrationstests, Benutzerakzeptanztests.
 • Beschreibung der Testumgebung und -tools.
 • Fehlerbehebung und Herausforderungen:
 • Konkrete Probleme während der Tests und ihre Lösungen.

8. Ergebnisse und Bewertung (3–4 Seiten)

 • Funktionalität: Übersicht über erreichte Ergebnisse, welche Ziele wurden erfüllt?
 • Leistungsbewertung: Wie performant ist das System? Gibt es Engpässe?
 • Feedback und Evaluation:
 • Falls vorhanden: Benutzerfeedback oder Testergebnisse.
 • Stärken und Schwächen:
 • Analyse, was gut gelungen ist und was verbessert werden könnte.

9. Fazit und Ausblick (2 Seiten)

 • Zusammenfassung:
 • Kernpunkte des Projekts und der Dokumentation.
 • Lernprozesse: Was wurde technisch und organisatorisch gelernt?
 • Weiterentwicklung:
 • Mögliche Erweiterungen (z.B. AI-basierte Cocktail-Vorschläge, Unterstützung für weitere Geräte).

10. Anhang (variabel)

 • Schaltpläne, vollständiger Code-Auszug (sofern relevant), Mockups.
 • Detaillierte Diagramme, zusätzliche Screenshots oder Testergebnisse.

11. Literaturverzeichnis (1–2 Seiten)

 • Alle verwendeten Quellen und Materialien.

Hinweise zur Umsetzung

 1. Technische Tiefe:
 • Setzt Schwerpunkte in den Abschnitten zur Hardware, Backend und App-Entwicklung, da diese die Kerntechnologien darstellen.
 • Verwendet klare Diagramme (z.B. Architektur, Datenflüsse, Schaltpläne) zur Veranschaulichung.
 2. Wissenschaftlicher Stil:
 • Arbeitet mit Referenzen zu technischen Dokumentationen, Artikeln oder Büchern, um die theoretischen Grundlagen abzusichern.
 • Nutzt präzise Formulierungen und Verweise auf Best Practices.
 3. Seitenanzahl:
 • Die Dokumentation sollte idealerweise 30–40 Seiten umfassen, wobei bei detaillierter Darstellung von Hardware oder Backend-Architektur auch eine längere Arbeit sinnvoll wäre.

Falls du noch weitere Anpassungen brauchst oder Unterstützung bei einem bestimmten Abschnitt möchtest, sag Bescheid!

---

# Visuelle Elemente für die Projektarbeit

- [ ] **Systemarchitektur (Diagramm)**  
  Ein Diagramm, das die Gesamtstruktur des Systems darstellt, einschließlich der Hardwarekomponenten (z. B. Automatenhardware, Pi), des Backends (Cloud, Datenbank) und der App (Benutzerschnittstelle, Kommunikation mit Backend).

- [ ] **Schaltpläne (Hardware-Architektur)**  
  Schaltpläne, die die elektrischen Verbindungen und Komponenten des Cocktailautomaten darstellen, einschließlich Verkabelung von Sensoren, Pumpen und Mikrocontrollern.

- [ ] **Benutzeroberfläche der App (Screenshots oder Mockups)**  
  Screenshots oder Mockups der Benutzeroberfläche der Smartphone-App, die Funktionen wie Rezeptverwaltung, Cocktailzubereitung und Steuerung darstellen.

- [ ] **Backend-Architektur (Datenflüsse)**  
  Diagramm, das den Datenfluss innerhalb des Backends zeigt, einschließlich der Kommunikation zwischen App, Cloud, Datenbank und Hardware.

- [ ] **Cloud-Datenbankstruktur (ER-Diagramm)**  
  Entity-Relationship-Diagramm (ERD), das die Struktur der Cloud-Datenbank darstellt, einschließlich Tabellen und deren Beziehungen.

- [ ] **Automatisierungsabläufe (Flowchart)**  
  Ein Flussdiagramm, das die Automatisierungslogik des Systems beschreibt – von der Benutzeranfrage über die Verarbeitung bis hin zur Steuerung der Hardwarekomponenten.

- [ ] **Testszenarien und Ergebnisse (Tabellen oder Diagramme)**  
  Tabellen oder Diagramme (Balken-, Linien- oder Tortendiagramme), die Testergebnisse wie Geschwindigkeit der Zubereitung, Genauigkeit der Mischung oder Benutzerfeedback darstellen.

- [ ] **Prototypenfotos (Fotos der Hardware)**  
  Fotos des tatsächlichen Prototyps des Cocktailautomaten, sowohl von außen als auch von den wichtigsten Hardwarekomponenten (z. B. Raspberry Pi, Sensoren, Pumpen).

- [ ] **Zeitraffer der Cocktailzubereitung (Video/GIF)**  
  Ein Video oder GIF, das den Cocktailautomaten bei der Zubereitung eines Cocktails zeigt – vom Benutzerbefehl bis zum fertigen Getränk.

- [ ] **Vergleichende Marktforschung (Balken- oder Tortendiagramme)**  
  Diagramme, die den Cocktailautomaten mit bestehenden Lösungen auf dem Markt vergleichen (z. B. Preise, Funktionsumfang, Skalierbarkeit).

- [ ] **Skalierbarkeit und Erweiterung (Modularitätsdiagramm)**  
  Ein Diagramm, das die Skalierbarkeit des Systems darstellt, z. B. wie mehrere Automaten zusammenarbeiten oder wie das System durch das Hinzufügen neuer Funktionen oder Komponenten erweitert werden kann.

- [ ] **Benutzerinteraktionen (Interaktionsdiagramme)**  
  Diagramme, die den Benutzerfluss innerhalb der App oder des Systems darstellen, z. B. wie der Benutzer mit der App interagiert, um Rezepte auszuwählen oder den Zubereitungsprozess zu starten.

- [ ] **Hardware-Tests (Messdaten oder Diagramme)**  
  Diagramme oder Tabellen, die die Ergebnisse von Hardware-Tests darstellen, z. B. Messungen zu den Pumpen, Sensoren oder dem Energieverbrauch des Systems.

- [ ] **Prototyp-Demonstration (Screenshots von Testphasen)**  
  Screenshots oder Fotos von wichtigen Testphasen des Prototyps, die die Funktionalität der einzelnen Komponenten und deren Zusammenwirken zeigen.

- [ ] **Fehlermeldungen und Debugging-Prozess (Screenshots oder Logs)**  
  Screenshots von Fehlermeldungen oder Logdateien, die den Debugging-Prozess dokumentieren und den Umgang mit auftretenden Problemen zeigen.

- [ ] **Benutzerdokumentation (Illustrationen oder Textscreenshots)**  
  Screenshots und Illustrationen, die den Endbenutzern helfen, den Cocktailautomaten und die App zu bedienen, sowie eine einfache Schritt-für-Schritt-Anleitung.

- [ ] **Funktionstests der App (Screenshots von Testszenarien)**  
  Screenshots der App, die spezifische Testszenarien demonstrieren, z. B. das Erstellen eines neuen Rezepts oder das Bearbeiten der Bestückung des Automaten.

- [ ] **Datenbankabfragen und -ergebnisse (Tabellen oder SQL-Auszüge)**  
  Tabellen oder Auszüge von SQL-Abfragen, die zeigen, wie Daten in der Cloud-Datenbank gespeichert und abgerufen werden.

- [ ] **Kostenschätzung und Wirtschaftlichkeitsanalyse (Diagramme oder Tabellen)**  
  Diagramme, die eine Schätzung der Kosten des Systems im Vergleich zu traditionellen Lösungen oder anderen Alternativen zeigen, sowie eine Wirtschaftlichkeitsanalyse.

- [ ] **Sicherheitsaspekte (Sicherheitsarchitektur oder Diagramme)**  
  Diagramme oder Abbildungen, die die Sicherheitsarchitektur des Systems darstellen, z. B. die Sicherstellung von Datenintegrität oder die Verschlüsselung von Benutzerdaten.

- [ ] **Zukunftsperspektiven und Erweiterungen (Prototyp-Entwicklungsplan)**  
  Ein Diagramm oder eine Roadmap, die die geplante Weiterentwicklung und Skalierung des Projekts aufzeigt, sowie mögliche zukünftige Erweiterungen des Systems.

- [ ] **Teamarbeit und Projektmanagement (Zeitleiste oder Gantt-Diagramm)**  
  Ein Gantt-Diagramm oder eine Zeitleiste, die den Verlauf des Projekts und die Aufgabenverteilung innerhalb des Teams darstellt.

- [ ] **Zusammenfassung der wichtigsten Ergebnisse (Bilder oder Diagramme)**  
  Ein Diagramm oder eine Grafik, die die wichtigsten Ergebnisse des Projekts zusammenfasst, z. B. die Anzahl erfolgreich zubereiteter Cocktails oder Benutzerfeedback.

- [ ] **Vergleich der ursprünglichen Anforderungen mit den tatsächlichen Ergebnissen (Tabellen)**  
  Eine Tabelle, die die Anforderungen des Projekts mit den tatsächlich erreichten Ergebnissen vergleicht.

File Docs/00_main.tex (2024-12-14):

\documentclass[a4paper, 12pt]{article} % A4-Seitenformat und Schriftgröße 12pt

% Pakete für Sprache, Schrift und andere wichtige Anpassungen
\usepackage[utf8]{inputenc} % UTF-8 Unterstützung für Umlaute
\usepackage[T1]{fontenc}    % Korrekte Silbentrennung bei Umlauten
\usepackage[ngerman]{babel} % Deutsche Spracheinstellungen (z. B. Texttrennung, Typografie)
\usepackage{csquotes}       % Korrekte deutsche Anführungszeichen („ “)
\usepackage{geometry}       % Seitenränder anpassen
\geometry{a4paper, left=3cm, right=3cm, top=2.5cm, bottom=2.5cm} % Beispiel für Seitenränder

\title{Automatisierter Smarter Cocktail-Automat mit Cloud Anbindung}
\author{ 
  Jonas Eck \\
	Technische Hochschule Würzburg-Schweinfurt\\
	\and 
	Phillip Schön \\
	Technische Hochschule Würzburg-Schweinfurt\\
	\and 
  Constantin Thein\\
	Technische Hochschule Würzburg-Schweinfurt\\
	}

\date{\today}

\begin{document}

\maketitle
\newpage
\tableofcontents
\newpage

\begin{abstract}
Im Rahmen dieses Projekts wurde ein smarter Cocktailautomat entwickelt, der wesentliche Elemente des
Internet of Things (IoT) mit den Anforderungen moderner Smart-Home-Lösungen verbindet. Ziel war die
Umsetzung eines skalierbaren Prototyps, der die automatisierte Zubereitung von Cocktails ermöglicht 
und dabei durch eine intuitive Bedienung über eine Smartphone-App sowie die Anbindung an ein 
cloudbasiertes Backend besticht.

Die Lösung umfasst drei Kernkomponenten: eine modular aufgebaute Hardware für die 
Cocktailzubereitung, ein containerisiertes Backend gehostet in Google Cloud Run mit einer 
Cloud-SQL-Datenbank sowie eine mobile App, die eine benutzerfreundliche Verwaltung von Rezepten, 
Zutaten und Maschinenkonfigurationen erlaubt. Besonderes Augenmerk wurde auf die Skalierbarkeit und 
Erweiterbarkeit des Systems gelegt, wodurch sowohl mehrere Benutzer als auch mehrere Automaten 
unterstützt werden können.

Das Projekt zeigt die Potenziale von IoT-Technologien auf, alltägliche Aufgaben zu automatisieren 
und dabei innovative Ansätze für Smart-Home-Umgebungen zu entwickeln. Gleichzeitig wurden 
Herausforderungen wie die Einarbeitung in neue Technologien, der Umgang mit komplexen 
Elektronikkomponenten sowie die effiziente Integration von Cloud-Diensten gemeistert.
\end{abstract}

% Hier werden die Unterdokumente eingebunden
\input{sections/01_einleitung}    % Datei einleitung.tex
\input{sections/02_technologischer_hintergrund}    % Technologischer Hintergrund und verwandte Arbeiten
\input{sections/03_anforderungen_und_konzept}    % Anforderungen und Konzept
\input{sections/04_umsetzung_hardware}    % Umsetzung der Hardware
\input{sections/05_backend_architektur_und_implementierung}    % Backend-Architektur und Implementierung
\input{sections/06_mobile_app_entwicklung}    % Mobile App-Entwicklung
\input{sections/07_integration_und_tests}    % Integration und Tests
\input{sections/08_ergebnisse_und_bewertung}    % Ergebnisse und Bewertung
\input{sections/09_fazit_und_ausblick}    % Fazit und Ausblick
\input{sections/10_anhang}    % Anhang
\input{sections/11_literaturverzeichnis}    % Literaturverzeichnis

\section{Technologischer Hintergrund und verwandte Arbeiten}(3–5 Seiten)
\section{Anforderungen und Konzept}(4–5 Seiten)
\section{Umsetzung der Hardware}(4–6 Seiten)
\section{Backend-Architektur und Implementierung}(4–6 Seiten)
\section{Mobile App-Entwicklung}(4–5 Seiten)
\section{Integration und Tests}(4–5 Seiten)
\section{Ergebnisse und Bewertung}(3–4 Seiten)
\section{Fazit und Ausblick}(2 Seiten)
\section{Anhang}(variabel)
\section{Literaturverzeichnis}(1–2 Seiten)

\section{Conclusions}\label{conclusions}
There is no longer \LaTeX{} example which was written by \cite{doe}.

\begin{thebibliography}{9}
\bibitem[Doe]{doe} \emph{First and last \LaTeX{} example.},
John Doe 50 B.C. 
\end{thebibliography}

\end{document}

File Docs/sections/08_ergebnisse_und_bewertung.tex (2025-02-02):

In diesem Abschnitt werden die erzielten Ergebnisse des Projekts beschrieben und kritisch bewertet. 
Der Fokus liegt auf der funktionalen Umsetzung, der Leistungsbewertung des Systems und einer Analyse 
der Stärken und Schwächen.

\subsection{Funktionale Ergebnisse}

Das Projektziel, einen voll funktionsfähigen Prototypen für einen smarten Cocktailautomaten zu 
entwickeln, wurde erfolgreich erreicht. Die wesentlichen funktionalen Anforderungen konnten 
umgesetzt werden:

\begin{itemize}
  \item \textbf{Automatisierte Cocktailzubereitung:} Die Hardware steuert präzise die Pumpen und 
  Motoren, um Zutaten gemäß den Rezeptvorgaben abzugeben.
  \item \textbf{Mobile App:} Benutzer können über eine intuitive App Rezepte erstellen, verwalten 
  und Bestellungen auslösen.
  \item \textbf{Backend-Integration:} Das Backend verarbeitet Bestellungen zuverlässig, 
  \\synchronisiert Benutzerdaten und leitet Steuerbefehle an die Hardware weiter.
\end{itemize}
Die abschließenden Integrationstests zeigten, dass das Gesamtsystem von der Rezeptbestellung in der 
App bis zur Zubereitung durch die Hardware stabil funktioniert.

\subsection{Leistungsbewertung der Pumpen}

Der Test der Pumpen ergab, dass die Dosiergenauigkeit der einzelnen Pumpen mitunter Stark abweicht. 
Die Leistung der Pumpen ist in Abbildung \ref{fig:pump_performance} dargestellt. Grund für das 
Abweichen der Pumpen 1 und 5 ist vermutlich ein Defekt durch eine anfänglich unsachgemäße 
Inbetriebnahme unsererseits. Die Pumpen 2, 3, 4 und 6 zeigen eine gute Leistung und eine geringe 
Abweichung. Die Pumpen 2, 3 und 4 sind dabei besonders genau und weisen eine geringe Abweichung auf.

Die Probleme der Pumpen lassen sich jedoch mittels einer Kalibrierung des Pumpfaktors beheben. 
Alternativ kann auch eine Zukünftige Verwendung der Waage das Problem beheben, da die Waage die
tatsächlich ausgegebene Menge misst und die Pumpen entsprechend rechtzeitig gestoppt werden können.

\begin{figure}[H] 
    \centering 
    \begin{tikzpicture} 
        \begin{axis}[ 
            boxplot/draw direction=y, 
            ylabel={ Menge in Milliliter }, % Beschriftung der y-Achse 
            xlabel={ Pumpen }, % Beschriftung der x-Achse
            xtick={ 1, 2, 3, 4, 5, 6 }, % Positionen der xticks 
            xticklabels={ 1, 2, 3, 4, 5, 6 }, % Labels der xticks
            ymin=210, 
            ymax=430, % Begrenzung der y-Achse 
            boxplot/every box/.style={solid}
            ] 
            \addplot [ 
                thick, dashed, blue, 
                domain=0:7, 
            ] {400}; 
            \addplot+ [ boxplot, fill=red4, draw=red7, solid ] 
            table[row sep=\\, y index=0] 
            { 
                370 \\ 375 \\ 357 \\ 364 \\ 358 \\ 362 \\ 382 \\ 383 \\ 370 \\ 366 \\ 370 \\ 368 \\ 
                383 \\ 373 \\ 360 \\ 355 \\ 373 \\ 381 \\ 356 \\ 349 \\ 362 \\ 370 \\ 369 \\ 361 \\ 
            }; 
            \addplot+ [ boxplot, fill=red4, draw=red7, solid ] 
            table[row sep=\\, y index=0] 
            { 
                399 \\ 388 \\ 395 \\ 395 \\ 399 \\ 409 \\ 402 \\ 400 \\ 386 \\ 401 \\ 400 \\ 400 \\ 
                404 \\ 387 \\ 405 \\ 400 \\ 400 \\ 390 \\ 388 \\ 400 \\ 400 \\ 399 \\ 405 \\ 399 \\ 
            }; 
            \addplot+ [ boxplot, fill=red4, draw=red7, solid ] 
            table[row sep=\\, y index=0] 
            { 
                397 \\ 402 \\ 395 \\ 398 \\ 400 \\ 400 \\ 395 \\ 400 \\ 402 \\ 400 \\ 399 \\ 408 \\ 
                395 \\ 388 \\ 403 \\ 400 \\ 402 \\ 400 \\ 408 \\ 388 \\ 396 \\ 408 \\ 397 \\ 390 \\ 
            }; 
            \addplot+ [ boxplot, fill=red4, draw=red7, solid ]
            table[row sep=\\, y index=0] 
            { 
                411 \\ 400 \\ 398 \\ 399 \\ 400 \\ 408 \\ 408 \\ 415 \\ 400 \\ 386 \\ 393 \\ 390 \\ 
                400 \\ 404 \\ 400 \\ 406 \\ 409 \\ 400 \\ 403 \\ 396 \\ 406 \\ 407 \\ 405 \\ 396 \\ 
            };
            \addplot+ [ boxplot, fill=red4, draw=red7, solid ] 
            table[row sep=\\, y index=0] 
            { 
                267 \\ 259 \\ 305 \\ 242 \\ 306 \\ 315 \\ 313 \\ 287 \\ 266 \\ 300 \\ 298 \\ 260 \\
                285 \\ 251 \\ 283 \\ 243 \\ 266 \\ 263 \\ 255 \\ 278 \\ 241 \\ 255 \\ 315 \\ 280 \\ 
            }; 
            \addplot+ [ boxplot, fill=red4, draw=red7, solid ] 
            table[row sep=\\, y index=0] 
            { 
                382 \\ 385 \\ 387 \\ 382 \\ 390 \\ 386 \\ 390 \\ 377 \\ 393 \\ 388 \\ 383 \\ 398 \\ 
            }; 
        \end{axis}
    \end{tikzpicture} 
    \caption{Boxplot: Pumpenleistung für 400ml} 
    \label{fig:pump_performance} 
\end{figure}

\subsection{Lasttestergebnisse und Analyse}
\label{subsec:lasttest_results}

Zur Bewertung der Performance und Skalierbarkeit des Systems wurden umfassende Lasttests mit dem 
Tool \texttt{k6} durchgeführt. Diese Tests simulierten eine Vielzahl gleichzeitiger 
Benutzeranfragen, um Engpässe und Optimierungspotenziale zu identifizieren. Die wichtigsten 
Ergebnisse sind im Folgenden zusammengefasst.

\subsubsection*{Gesamtergebnisse}

\subsubsection*{Wichtige Metriken}
\begin{itemize}
    \item \textbf{Gesamtanfragen:} 16.506
    \item \textbf{Fehlerrate:} 0,08\% (14 fehlgeschlagene Anfragen)
    \item \textbf{Durchschnittliche Antwortzeit:} 274,48 ms
    \item \textbf{Minimale Antwortzeit:} 13,87 ms
    \item \textbf{Median der Antwortzeit:} 19,75 ms
    \item \textbf{Maximale Antwortzeit:} 282.415,99 ms
    \item \textbf{90. Perzentil der Antwortzeit:} 78,66 ms
    \item \textbf{95. Perzentil der Antwortzeit:} 121,84 ms
\end{itemize}

% ERFOLGSRATE --------------------------------------------------------------------------------------
\subsubsection*{Erfolgsrate}

\begin{table}[H]
    \centering
    % \resizebox{\textwidth}{!}{%
        \begin{tabular}{|l|r|r|r|}
            \hline
            \textbf{Test} & \textbf{Erfolgreich} & \textbf{Fehlgeschlagen} & \textbf{Erfolgsrate} \\
            \hline
            Nutzerregistrierung   &  263 &   0 &  100\% \\
            Nutzer einloggen      &  263 &   0 &  100\% \\
            Hardwareregistrierung &  262 &   1 &   99\% \\
            Drink erstellen       & 2615 &   5 &   99\% \\
            Slot setzen           & 1304 &   6 &   99\% \\
            Rezept erstellen      & 2619 &   1 &   99\% \\
            Zutat hinzufügen      & 2620 &   0 &  100\% \\
            Favorit erstellen     &  785 &   1 &   99\% \\
            Slots abfragen        &  262 &   0 &  100\% \\
            Favoriten abfragen    &  263 &   0 &  100\% \\
            \hline
        \end{tabular}
    % }
    \caption{Tests je Endpunkt und Erfolgsrate}
    \label{tab:test_success_rate}    
\end{table}

Die Erfolgsrate der einzelnen API-Endpunkte ist insgesamt hoch. Die Nutzerregistrierung und das 
Einloggen waren zu 100\% erfolgreich, während die Hardwareregistrierung eine Erfolgsrate von 99\% 
aufweisen. Die Fehlerrate bei der Erstellung von Getränken und Rezepten, dem setzen von Slots und 
dem hinzufügen von Bestandteilen zu einem Rezept liegt bei 1\%. Diese Fehler lassen sich aber 
allesamt durch das Fehlschlagen der Hardwareregistrierung erklären, da diese für einen Eintrag in 
die Datenbank benötigt wird. Die Erfolgsrate der Favoritenfunktion liegt aus dem selben Grund 
lediglich bei 99\%. Alles in allem sind die Ergebnisse zufriedenstellend. 
Das scheitern der Hardware registrieren Anfrage ist auf eine Auslastung der Container Instanz 
zurückzuführen, und könnte mit mehr Leistung, mit weiteren Container Instanzen oder einer 
Optimierung der Anfrage behoben werden.

% ANTOWRTZEITEN ------------------------------------------------------------------------------------
\subsubsection*{Antwortzeiten pro Endpunkt}

Die Antwortzeiten für spezifische API-Endpunkte zeigen deutliche Unterschiede, die auf 
unterschiedliche Verarbeitungskomplexität hinweisen. Die wichtigsten Werte sind in Tabelle 
\ref{tab:response_times} dargestellt.

\begin{table}[H] 
    \centering
    % \resizebox{\textwidth}{!}{%
        \begin{tabular}{|l|r|r|r|r|}
            \hline
            \textbf{Endpunkt} &
            \textbf{Durchschnitt} & 
            \textbf{Median} & 
            \textbf{90. Perzentil} & 
            \textbf{Max} \\
            \hline
            Nutzer registrieren     &  145,60 & 102,70 & 219,23 &   1224,98 \\
            Nutzer einlogen         &  155,90 & 102,51 & 283,79 &   1530,31 \\
            Hardware registrieren   & 1241,48 &  70,54 & 218,08 & 282415,99 \\
            Drink erstellen         &  588,13 &  19,39 &  52,83 & 282275,98 \\
            Rezept erstellen        &  136,98 &  19,10 &  42,42 & 282282,60 \\
            Zutat hinzufügen        &   29,39 &  18,85 &  46,66 &    422,70 \\
            Slot setzen             & 1341,94 &  23,35 &  79,69 & 282292,87 \\
            Rezept favorisieren     &  268,85 &  24,01 &  64,44 & 183405,20 \\
            Alle Favoriten abfragen &   29,58 &  20,01 &  51,67 &    227,09 \\
            Slotbelegung abfragen   &   64,92 &  48,96 & 112,32 &    355,33 \\
            \hline
        \end{tabular}
    % }
    \caption{Antwortzeiten je Endpunkt in Millisekunden}
    \label{tab:response_times}
\end{table}

Bei einer genaueren Betrachtung der Antwortzeiten pro Endpunkt fällt auf, dass die Endpunkte mit 
den höchsten Maximalwerten (Hardware registrieren, Drink erstellen, Rezept erstellen, Slot setzen, 
Favorit setzen) wieder die selben Punkte sind welche bereits zuvor als fehleranfällig identifiziert
wurden. Die Antwortzeiten sind in diesen Fällen sehr hoch, was auf eine Überlastung der Container 
Instanz zurückzuführen ist. Die Antwortzeiten der anderen Endpunkte sind im Vergleich dazu sehr
gering. Die Antwortzeiten der Endpunkte Zutat hinzufügen, Alle Favoriten abfragen und Slotbelegung
abfragen sind besonders niedrig, was auf eine geringe Verarbeitungskomplexität hinweist.

\hyphenation{Live-Umgebung}
\hyphenation{Web-socket-Ver-bind-ung}
Die Tests haben gezeigt, dass das System in einer Live-Umgebung grundsätzlich stabil arbeitet. 
Allerdings wurden Skalierungsprobleme bei Websocket-Verbindungen identifiziert, die durch eine 
zentrale Verwaltung oder eine konsistente Lastverteilung gelöst werden könnten. Die meisten API-
Endpunkte zeigten zufriedenstellende Antwortzeiten und Erfolgsquoten. Die Schwachstellen bieten 
jedoch Anknüpfungspunkte für zukünftige Optimierungen.

% USABILITY ----------------------------------------------------------------------------------------
\subsection{User-Test Ergebnisse}

Zur Evaluation der Benutzerfreundlichkeit, des Funktionsumfangs und der Stabilität der mobilen App 
wurden neun Personen eingeladen, die App zu testen. Sie bewerteten die App in den drei Kategorien 
auf einer Skala von 1 (schlecht) bis 5 (sehr gut). Die Ergebnisse sind in Tabelle 
\ref{tab:user_tests} und in der Visualisierung in Abbildung \ref{fig:user_tests2} dargestellt.

\begin{table}[h!]
    \centering
    \renewcommand{\arraystretch}{1.2} % Erhöht den Zeilenabstand (Standard ist 1.0)
    \begin{tabular}{|l|c|}
        \hline
        \textbf{Kategorie} & \textbf{Durchschnittliche Bewertung} \\
        \hline
        Benutzerfreundlichkeit & $4.\overline{4}$ \\
        Funktionsumfang & $4.\overline{2}$ \\
        Stabilität und Leistung & $4.\overline{8}$ \\
        \hline
    \end{tabular}
    \renewcommand{\arraystretch}{1.0} % Setzt den Standardwert zurück
    \caption{Ergebnisse der Benutzerbewertungen}
    \label{tab:user_tests}
\end{table}

\begin{figure}[h!]
    \centering
    \begin{minipage}{0.80\textwidth}
        \centering
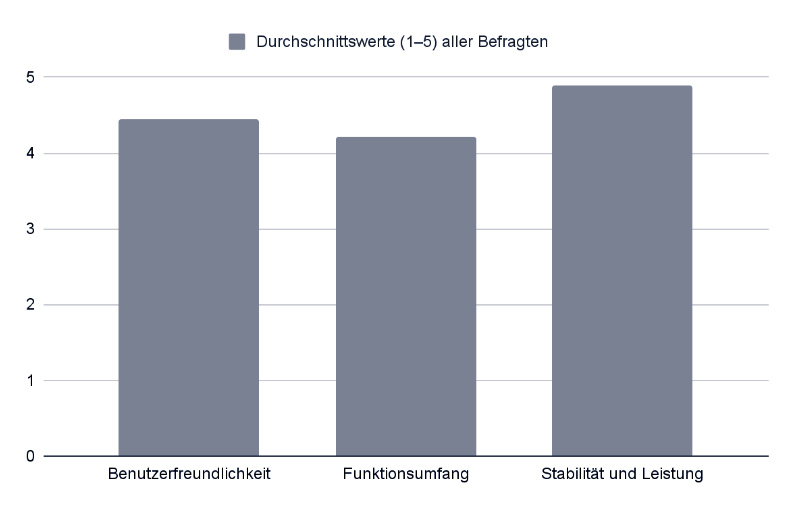
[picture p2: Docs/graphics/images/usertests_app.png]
        
        \caption{Usertest}
        \label{fig:user_tests2} % Direkt nach der caption setzen
    \end{minipage}
\end{figure}

\subsection{Stärken und Schwächen}

\subsubsection{Stärken}

Das Projekt weist folgende Stärken auf:
\begin{itemize}
  \item \textbf{Benutzerfreundlichkeit:} Die App bietet eine intuitive Benutzeroberfläche und 
  ermöglicht eine einfache Verwaltung von Rezepten und Geräten.
  \item \textbf{Technische Umsetzung:} Die Kombination aus App, Backend und Hardware zeigt das 
  Potenzial von IoT-Technologien in Smart-Home-Umgebungen.
  \item \textbf{Modularität:} Die Architektur des Systems ermöglicht zukünftige Erweiterungen, z. B. 
  die Integration zusätzlicher Geräte oder neue Funktionen.
\end{itemize}

\subsubsection*{Schwächen}

Einige Schwächen des aktuellen Prototyps wurden identifiziert:
\begin{itemize}
  \item \textbf{Skalierbarkeit:} Die Verwaltung von Websocket-Verbindungen in einer 
  containerisierten Umgebung führte bei hoher Last zu Problemen.
  \item \textbf{Fehlende Tests:} Es wurden keine umfassenden automatisierten Tests für die einzelnen 
  Systemkomponenten implementiert.
  \item \textbf{Hardware:} Obwohl die Hardware zuverlässig arbeitet, könnten Optimierungen in der 
  Dosiergenauigkeit und Stabilität vorgenommen werden.
\end{itemize}

\subsection{Zusammenfassung der Ergebnisse}

Das Projekt hat gezeigt, dass IoT-Technologien erfolgreich zur Automatisierung von Alltagsaufgaben 
eingesetzt werden können. Die entwickelten Systeme arbeiten zuverlässig und erfüllen die definierten 
funktionalen Anforderungen. Gleichzeitig wurden Schwächen aufgedeckt, die als Grundlage für 
zukünftige Optimierungen dienen können.

\subsection{Empfehlungen}
\hyphenation{Web-socket-Ser-ver}
Auf Basis der Testergebnisse und identifizierten Schwächen werden folgende Maßnahmen für zukünftige 
Verbesserungen empfohlen:
\begin{itemize}
  \item \textbf{Optimierung der Skalierung:} Einführung eines zentralen Websocket-Servers oder 
  konsistenter Lastverteilung, um Kommunikationsprobleme bei hoher Last zu beheben.
  \item \textbf{Automatisierte Tests:} Entwicklung und Implementierung umfassender \\
  Unit- und Integrationstests.
  \item \textbf{Hardware-Optimierungen:} Verbesserung der Dosiergenauigkeit und Integration 
  zusätzlicher Sensorik zur Überwachung.
\end{itemize}

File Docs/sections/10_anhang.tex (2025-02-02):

% Hier folgt der Inhalt des Abschnitts "Anhang".

\subsection{Pinbelegung}

\begin{figure}[ht]
  \centering
  
  \caption{Pinbelegung des Rapsberry Pi Zero 2 W}
  \label{fig:pinning}
\end{figure}

\newpage

\subsection{Schaltplan}

\begin{figure}[ht]
  \centering
  
  \caption{Schaltplan der Hardwarekomponenten}
  \label{fig:schaltplan}
\end{figure}

\newpage
\subsection{Datenbankschema}

\begin{figure}[H]
  \centering
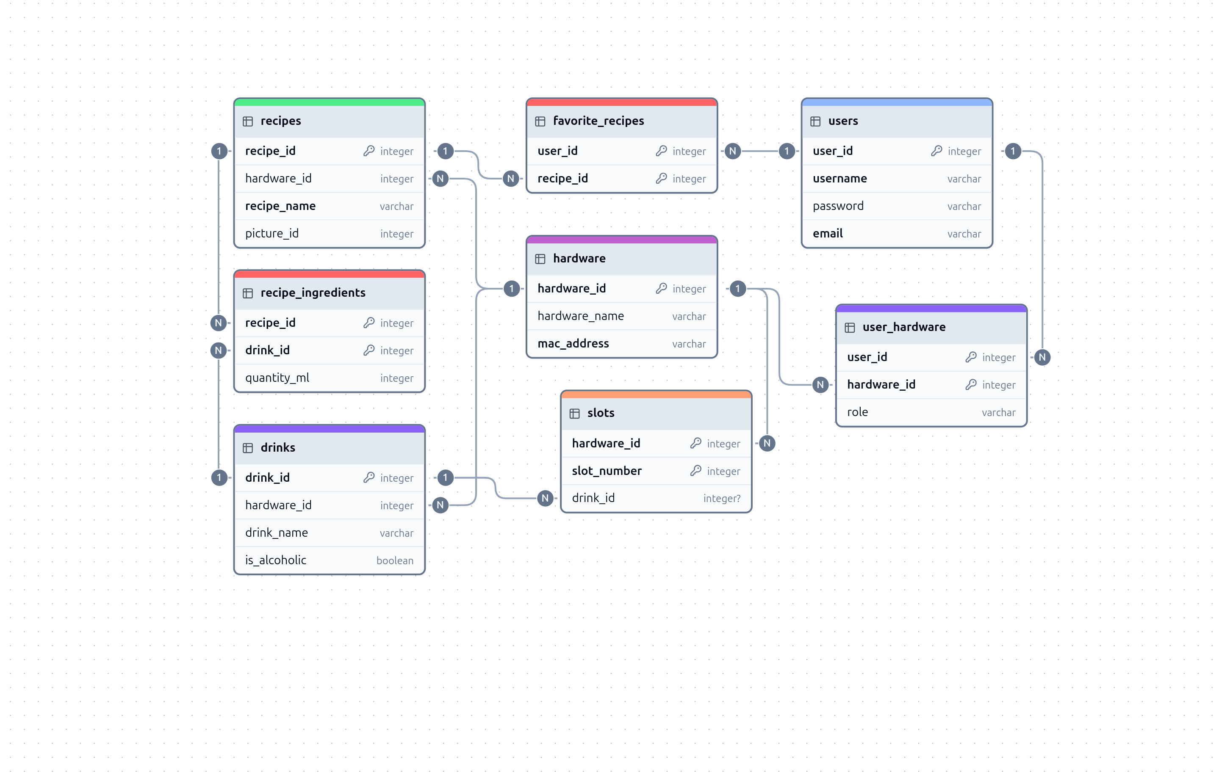
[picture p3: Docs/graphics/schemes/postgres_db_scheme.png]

  \caption{Datenbankdiagramm}
  \label{fig:database_diagram}
\end{figure}

\newpage

\include{graphics/listings/k6_script}

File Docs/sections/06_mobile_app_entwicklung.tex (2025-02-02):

Die mobile App wurde mit Flutter\cite{flutter} entwickelt, um eine 

plattformübergreifende Verfügbarkeit sowohl für Android als auch für iOS sicherzustellen. Flutter ermöglichte es, eine einzige Codebasis für beide Plattformen zu nutzen, wodurch der Entwicklungsaufwand reduziert und eine konsistente Benutzererfahrung gewährleistet wurde. Diese Entscheidung wurde getroffen, um die App möglichst effizient zu gestalten und gleichzeitig ein breites Publikum zu erreichen.

\subsection{Funktionen der App}
Die App bietet eine Vielzahl von Funktionen, die speziell auf die Verwaltung und Nutzung des Smartenders abgestimmt sind. Sie wurde so konzipiert, dass Benutzer sowohl die Steuerung des Smartenders als auch die Verwaltung von Rezepten und Zutaten übernehmen können. Zu den wichtigsten Funktionen gehören:

\begin{itemize}
    \item \textbf{Rezepte erstellen, ändern und löschen:} Benutzer können eigene Cocktailrezepte anlegen und diese flexibel verwalten.
    \item \textbf{Zutaten hinzufügen, ändern und löschen:} Die App erlaubt die Organisation und Anpassung der verfügbaren Zutaten.
    \item \textbf{Eingesteckte Flaschen (Zutaten) festlegen und ändern:} Es kann definiert werden, welche Zutaten in welchen Slots des Smartenders verfügbar sind.
    \item \textbf{Bestellungen auslösen:} Die App ermöglicht das direkte Auslösen von Cocktailbestellungen am Smartender.
    \item \textbf{Rezepte favorisieren:} Häufig genutzte Rezepte können als Favoriten markiert und schnell abgerufen werden.
    \item \textbf{Light- und Darkmode:} Benutzer können zwischen einem hellen und dunklen Designmodus wechseln, um die App an ihre Präferenzen anzupassen.
\end{itemize}
Die Integration mit einem zentralen Backend sorgt dafür, dass alle Daten synchronisiert
und jederzeit auf dem neuesten Stand sind. Dadurch können Benutzer Rezept- und
Zutatenlisten von mehreren Geräten aus abrufen und bearbeiten.

\subsection{Benutzeroberfläche (UI) und Design}
Die App verfolgt ein minimalistisches und intuitives Design, 
das Elemente des Material Designs integriert, ohne ein dediziertes Design-Framework\cite{materialdesign} 
zu nutzen. Das Ziel war es, die Benutzeroberfläche so einfach und zugänglich wie möglich zu gestalten, damit sie auch von technisch weniger erfahrenen Nutzern problemlos bedient werden kann.

Die Struktur der App umfasst mehrere zentrale Bereiche:

\begin{itemize}
    \item \textbf{Login- und Registrierungs-Screens:} Diese erscheinen nur, wenn ein Benutzer sich neu registrieren oder nach einem ausgelaufenen Token erneut einloggen möchte. Dadurch wird der Workflow für eingeloggte Benutzer vereinfacht.
    \item \textbf{Hauptscreens:} Drei Hauptscreens sind über eine Bottom-Navigationsleiste zugänglich:
    \begin{itemize}
        \item \textbf{Rezepte-Screen:} Zeigt eine Liste aller gespeicherten Rezepte an und bietet Optionen zur Bearbeitung oder Löschung.
        \item \textbf{Favoriten-Screen:} Zeigt nur die als Favoriten markierten Rezepte an und ist ähnlich dem Rezepte-Screen aufgebaut.
        \item \textbf{Einstellungen-Screen:} Ermöglicht die Verwaltung von Rezepten, Zutaten und Slots, das Wechseln des Designs zwischen Light- und Darkmode sowie das Ausloggen.
    \end{itemize}
\end{itemize}

\begin{figure}[H]
    \centering
    \begin{minipage}{0.27\textwidth}
        \centering
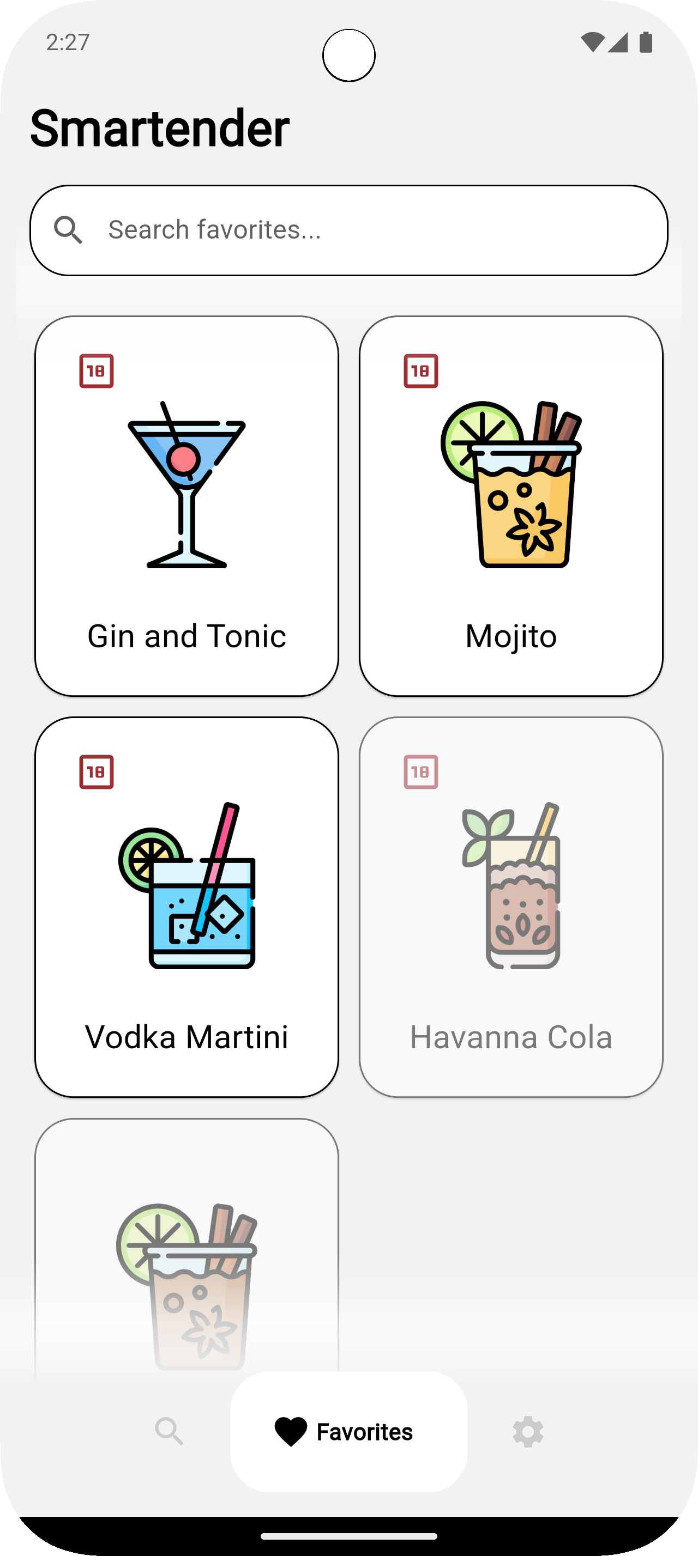
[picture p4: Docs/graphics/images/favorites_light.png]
        
        \caption{Favoritenansicht im Lightmode}
        \label{fig:favorites_light}
    \end{minipage}
    \hfill
    \begin{minipage}{0.27\textwidth}
        \centering
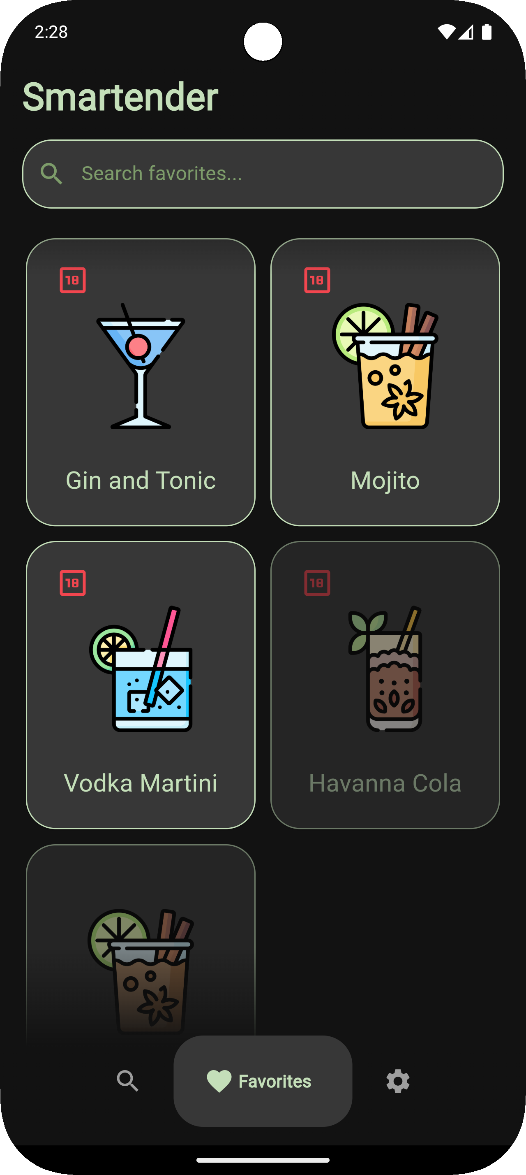
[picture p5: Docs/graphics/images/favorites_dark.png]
        
        \caption{Favoritenansicht im Darkmode}
        \label{fig:favorites_dark}
    \end{minipage}
    \hfill
    \begin{minipage}{0.27\textwidth}
        \centering
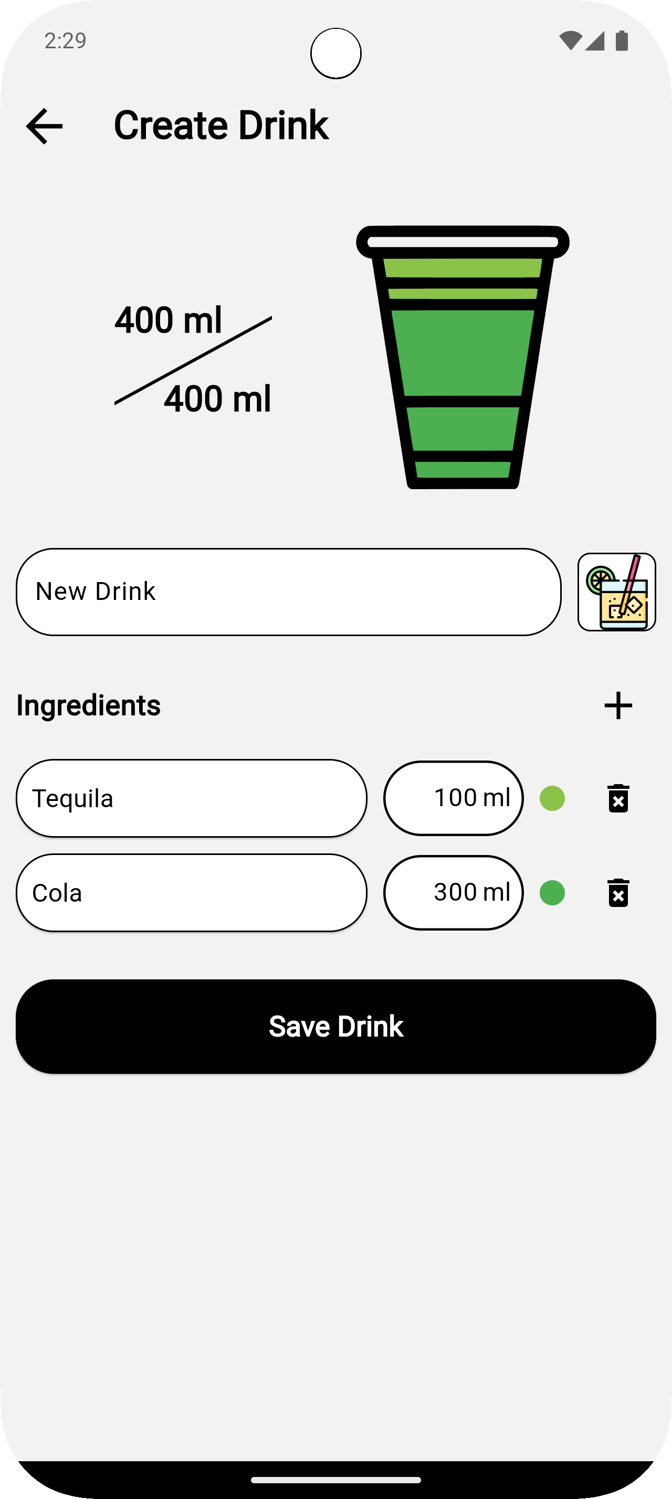
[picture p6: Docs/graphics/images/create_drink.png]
        
        \caption{Createdrinkscreen im Lightmode}
        \label{fig:create_drink}
    \end{minipage}
    \label{fig:favorites}
\end{figure}

\subsection{Integration und Kommunikation}
Die App kommuniziert über eine REST-API mit dem Backend, wodurch Daten wie Benutzerrezepte, Zutaten und Bestellungen synchronisiert werden. Diese Architektur ermöglicht eine nahtlose Integration und stellt sicher, dass alle Geräte jederzeit auf aktuelle Daten zugreifen können. Die REST-API stellt Endpunkte für folgende Aufgaben bereit:

\begin{itemize}
    \item Abruf und Aktualisierung von Benutzerinformationen
    \item Verwaltung von Rezepten und Zutaten
    \item Auslösen und Überwachung von Bestellungen
\end{itemize}
Eine wichtige Optimierung in der App war die Reduzierung unnötiger Backend-Aufrufe. Ursprünglich wurden Daten alle 10 Sekunden automatisch aktualisiert, was zu einer hohen Serverlast führen konnte. Dies wurde so angepasst, dass die Aktualisierung nur erfolgt, wenn ein Benutzer zwischen den Hauptscreens wechselt. Dadurch konnte die Performance des Systems deutlich verbessert werden.

\subsection{Entwicklungsprozess}
Während der Entwicklung stellten sich einige Herausforderungen, insbesondere bei der Anpassung der App an verschiedene Bildschirmauflösungen. Obwohl Flutter eine responsive Gestaltung ermöglicht, trat bei Tests auf dem Samsung S24 Ultra ein Overflow-Fehler auf, der bei Geräten mit geringerer Auflösung nicht auftrat. Dieses Problem wurde jedoch erfolgreich identifiziert und behoben, sodass die App nun auf unterschiedlichen Displaygrößen einwandfrei funktioniert.
Zur Entwicklung wurden folgende Tools genutzt:

\begin{itemize}
    \item \textbf{Android Studio:} Hauptentwicklungsumgebung für Android.
    \item \textbf{Postman:} Testen der REST-API-Schnittstellen.
    \item \textbf{Xcode:} Build-Prozess und Tests für iOS-Geräte.
\end{itemize}
Um technische Details zu überprüfen und Designentscheidungen zu bewerten, wurden mehrere Testversionen der App erstellt. Diese wurden unter den Entwicklern getestet, um Fehler zu identifizieren und Verbesserungen vorzunehmen. Dieser iterative Ansatz ermöglichte eine kontinuierliche Optimierung der App.

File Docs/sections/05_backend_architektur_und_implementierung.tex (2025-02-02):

% Hier folgt der Inhalt des Abschnitts "Backend-Architektur und Implementierung".
Das Backend bildet das zentrale Bindeglied zwischen der mobilen App, der Hardwarekomponente des 
Cocktailautomaten und der cloudbasierten Datenbank. Es ist dafür verantwortlich, Datenflüsse zu 
koordinieren, Benutzer- und Rezeptinformationen zu verwalten und eine nahtlose Kommunikation 
zwischen den Systemkomponenten zu gewährleisten.

\subsection{Allgemeine Architektur}

Das Backend folgt einer einfachen serverbasierten Struktur und stellt HTTP - Endpunkte bereit, die 
von der mobilen App aufgerufen werden können. Diese Endpunkte aktivieren spezifische Handler-
Funktionen, die in der Regel direkte Datenbankoperationen ausführen. Zusätzlich ermöglicht das 
Backend über eine Websocket-Schnittstelle die Kommunikation mit der Hardware, um Bestellungen in 
Echtzeit an die Geräte weiterzuleiten.

Technologisch basiert das Backend vollständig auf Golang, unterstützt durch Frameworks wie \texttt{
gorilla/ mux} für die Routenverwaltung und \texttt{database/sql} für den Zugriff auf die PostgreSQL 
- Datenbank. Die gesamte Umgebung ist containerisiert und nutzt Docker Compose für lokale 
Entwicklungsumgebungen sowie Google Cloud Run für das Live-Deployment. In der Live-Umgebung wird 
Google Cloud SQL anstelle einer lokalen PostgreSQL-Datenbank eingesetzt.

\subsection{Funktionale 
Anforderungen}

Das Backend übernimmt mehrere Kernfunktionen:

\begin{itemize}
	\item \textbf{Benutzerdatenverwaltung:} Erstellung und Authentifizierung von Benutzerkonten 
	mittels API- Schlüsseln und JWT.
	\item \textbf{Rezept- und Zutatenmanagement:} Speicherung, Bearbeitung und Abfrage von Rezepten 
	und deren zugehörigen Zutaten.
	\item \textbf{Hardwareintegration:} Verwaltung der Hardwaregeräte, ihrer Zuordnung zu Benutzern 
	und ihrer Bestückung.
	\item \textbf{Echtzeit-Bestellungen:} Weiterleitung von Cocktailbestellungen aus der App an die 
	angeschlossene Hardware über Websockets.
\end{itemize}
\hyphenation{Echt-zeit-kom-mu-ni-ka-tion}
\hyphenation{Web-socket-Ver-bin-dung}
Besonders anspruchsvoll ist die Echtzeitkommunikation zwischen App und Hardware. Sobald eine 
Bestellung eingeht, wird das Rezept aus der Datenbank abgerufen und über die Websocket-Verbindung 
an die entsprechende Hardware weitergeleitet. Dies ermöglicht eine nahezu sofortige Ausführung der 
Bestellung.

\subsection{Datenbank}

Für die Datenhaltung kommt PostgreSQL zum Einsatz. Die Datenbank ist in der lokalen 
Entwicklungsumgebung als Docker-Container verfügbar, während im Deployment auf Google Cloud SQL 
gesetzt wird. Zu den gespeicherten Entitäten gehören unter anderem Benutzer, Hardwaregeräte, 
Rezepte, Zutaten und deren Zuordnungen.

Das Datenbankschema \ref{fig:database_diagram} wird im Anhang dokumentiert, um die Arbeit kompakt zu 
halten. Der Datenbankzugriff erfolgt mittels \texttt{database/sql} und direkter SQL-Statements. 
Durch diese Methode wird SQL-Injection auf Basis von Best Practices effektiv verhindert.

\subsection{API und 
Schnittstellen}

Die Backend-API ist primär REST-orientiert, verwendet jedoch keine Hypermedia-Links, da sie nicht 
für den öffentlichen Gebrauch konzipiert ist. Zu den wichtigsten Endpunkten gehören:

\vspace{0.5cm}
\textbf{Benutzerregistrierung und - login:}
\begin{enumerate}
  \item \texttt{/api/auth/register}
  \item \texttt{/api/auth/login}
\end{enumerate}

\vspace{0.5cm}
\textbf{Hardware- und Rezeptverwaltung:}
\begin{enumerate}
	\item \texttt{/api/user/hardware/\{hardware\_id\}/drinks}
	\item \texttt{/api/user/hardware/\{hardware\_id\}/recipes/\{recipe\_id\}}
	\item \texttt{/api/user/hardware/\{hardware\_id\}/slots}
\end{enumerate}

\vspace{0.5cm}
\textbf{Cocktailbestellungen:}
\begin{enumerate}
  \item \texttt{/api/user/action}
\end{enumerate}

Die Authentifizierung erfolgt durch eine Kombination aus API-Schlüsseln für allgemeine API-Zugriffe, 
Hardware-spezifischen Schlüsseln und JWT für Benutzerzugriffe .

\subsection{Cloud-Dienste und Infrastruktur}

Das Backend verwendet mehrere Dienste von Google Cloud:

\hyphenation{con-tai-ner-i-sier-ten}
\hyphenation{Back-end-An-wen-dung}
% TODO: fix hyphenation to fix overfull hbox in 'containerisierten Backend-Anwendung'
\begin{itemize}
	\item \textbf{Google Cloud Run:} Für das Hosting der containerisierten\\
	Backend-Anwendung\cite{googlecloudrun}.
	\item \textbf{Google Cloud SQL:} Für die zentrale Datenhaltung\cite{googlecloudsql}.
	\item \textbf{Google Artifact Registry:} Zur Verwaltung von Container-Images\cite{googleartifactregistry}.
	\item \textbf{Cloud Logging:} Zur Erfassung und Analyse von Backend-Logs\cite{googlecloudlogging}.
\end{itemize}
Skalierbarkeit ist durch die Nutzung von Google Cloud Run gegeben, da die Container automatisch 
skaliert werden können. Aktuell ist diese Funktion jedoch deaktiviert, um das Gratiskontingent von 
Google nicht zu überschreiten.

\subsection{Sicherheitsaspekte}

Für die Sicherheit wurden die folgenden Maßnahmen implementiert:
\begin{itemize}
	\item \textbf{HTTPS:} Sämtliche Datenübertragungen erfolgen verschlüsselt.
	\item \textbf{SQL-Injection-Schutz:} Durch die Verwendung von database/sql wird sichergestellt, 
	dass keine unsicheren SQL-Statements ausgeführt werden.
	\item \textbf{API-Schlüssel und JWT:} Nur authentifizierte Benutzer und Hardwaregeräte können auf 
	die entsprechenden Ressourcen zugreifen.
\end{itemize}

\subsection{Implementierungsdetails}

Während der Entwicklung traten keine größeren Herausforderungen auf, abgesehen von anfänglichen 
Problemen mit dem Hosting, die durch den Wechsel zu Google Cloud Run gelöst wurden. Die 
Echtzeitkommunikation zwischen Hardware und Backend wurde erfolgreich über Websockets umgesetzt, 
um eine sofortige Reaktion auf Benutzeranfragen zu gewährleisten.

\subsection{Entwicklungsprozess}

Zur Unterstützung des Entwicklungsprozesses wurden folgende Tools und Best Practices genutzt:
\begin{itemize}
	\item \textbf{Postman:} Für die Erstellung und das Testen von API-Endpunkten, teils auch automatisiert.
	\item \textbf{Intensives Logging:} Um Debugging und Fehleranalyse zu erleichtern.
	\item \textbf{Code Reviews und Code Pairing:} Zur Qualitätssicherung.
	\item \textbf{Agile Methoden:} Planung und Umsetzung erfolgten in Sprints mithilfe eines Ticketsystems.
\end{itemize}

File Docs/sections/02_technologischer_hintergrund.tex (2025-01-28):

\subsection{IoT und Smart-Home-Systeme}
Im Rahmen dieses Projekts definieren wir das Internet of Things (IoT) als eine Hardwareanwendung, 
die über eine Internetverbindung steuerbar ist. Der Cocktailautomat lässt sich durch eine mobile 
App aus der Ferne bedienen, wobei besonders der Cloud-Aspekt und die Integration der Steuerung über 
das Internet hervorzuheben sind. Die Wahl eines standardisierten IoT-Protokolls wie MQTT, Zigbee 
oder BLE wurde bewusst vermieden. Stattdessen wird die Kommunikation ausschließlich über das 
HTTP-Protokoll abgewickelt, was eine einfache Implementierung und Wartung ermöglicht.

\subsection{Hardware}
Für die Hardwareplattform fiel die Wahl auf den Raspberry Pi Zero 2 W. Der Pi wurde aufgrund seiner 
einfachen Programmierbarkeit und der Verfügbarkeit relevanter Python-Bibliotheken ausgewählt. 
Zunächst war auch eine Lösung zur WLAN-Konfiguration des Raspberry Pi über die App angedacht, konnte 
jedoch aufgrund technischer Schwierigkeiten nicht im zeitlichen Rahmen der Arbeit realisiert werden. 
Der Automat nutzt einen Steppermotor, einen Linearmotor, sechs Membranpumpen, zwei Mikroendschalter, 
sowie eine Waage.

\subsection{Backend und Cloud-Technologien}
Das Backend des Systems basiert auf Google Cloud Run, da es einfach aufzusetzen ist und zu Beginn 
ein kostenloses Guthaben von 300 US-Dollar bietet. Cloud Run ermöglicht die schnelle Bereitstellung 
von Containern, was die Skalierbarkeit und Wartbarkeit des Systems vereinfacht. Die 
Containerisierung des Backends sorgt für eine saubere Trennung der Anwendungslogik und die einfache 
Verwaltung der Software. Cloud SQL wurde als Datenbanklösung gewählt, da es eine hochverfügbare und 
ausfallsichere Lösung bietet und sich gut in die Google Cloud-Umgebung integriert. Als 
Programmiersprache wurde Go verwendet, ergänzt durch Bibliotheken wie \texttt{Mux}, um HTTP-Routen 
zu verwalten.

\subsection{Datenbank und API}
Für das Backend wurde eine relationale Datenbanklösung mit PostgreSQL genutzt, die aufgrund der 
guten Vorkenntnisse im Team und der Zuverlässigkeit der Technologie ausgewählt wurde. Die 
Tabellenmodelle für Cocktails und Zutaten wurden so entwickelt, dass eine effiziente und flexible 
Speicherung von Cocktailrezepten und Benutzerinformationen möglich ist. Als API-Technologie wurde 
eine REST-ähnliche Architektur gewählt, bei der statische Endpunkte definiert wurden, um Anfragen 
zu verarbeiten.

\subsection{Mobile App-Entwicklung}
Die mobile App wurde mit dem Framework \texttt{Flutter} entwickelt, da es die Möglichkeit bietet, 
für verschiedene Plattformen (iOS und Android) gleichzeitig zu entwickeln. Dies spart 
Entwicklungszeit und stellt sicher, dass die App auf mehreren Geräten konsistent funktioniert. 
Das Design der App orientiert sich an modernen ästhetischen Prinzipien, mit dem Ziel, eine 
benutzerfreundliche und ansprechende Oberfläche zu schaffen.

\subsection{Sicherheitsaspekte}
Sicherheitsmechanismen wurden sowohl im Backend als auch in der App implementiert. Wichtige 
API-Endpunkte sind durch API-Schlüssel abgesichert, wobei für die Kommunikation zwischen der App 
und der Hardware unterschiedliche Schlüssel verwendet werden. Zudem werden Endpunkte, die auf 
benutzerspezifische Daten zugreifen, mit JSON Web Tokens (JWT) geschützt, um sicherzustellen, 
dass nur autorisierte Benutzer auf ihre eigenen Daten zugreifen können. Die Kommunikation zwischen 
den Komponenten erfolgt über HTTPS, was eine sichere Übertragung der Daten gewährleistet.

\subsection{Weitere Technologien und Tools}
Für das Projekt wurde intensiv Docker und Docker Compose eingesetzt, um eine konsistente Umgebung 
für die Entwicklung und das Deployment zu schaffen. Dadurch wird sichergestellt, dass die Anwendung 
sowohl lokal als auch in der Cloud identisch läuft, was die Entwicklung und Wartung des Systems 
erheblich vereinfacht.

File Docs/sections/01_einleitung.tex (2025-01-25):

\subsection{Motivation}
Die Idee eines smarten Cocktailautomaten entstand im Kontext unserer Erfahrungen beim Organisieren 
und Betreiben von Cocktailbars auf Fakultätsveranstaltungen. Diese praktischen Erfahrungen zeigten, 
wie zeitaufwendig die manuelle Zubereitung von Cocktails insbesondere bei hohem Gästeaufkommen sein 
kann. Mit der zunehmenden Verbreitung von Smart-Home-Geräten und IoT - Lösungen kam die Idee auf, 
diesen Prozess durch Automatisierung zu vereinfachen und so die Cocktailzubereitung effizienter und 
benutzerfreundlicher zu gestalten. 
\\
Ein weiterer Beweggrund war die Möglichkeit, aktuelle Technologien wie Cloud-Computing und mobile 
Anwendungen in einer praxisnahen IoT - Anwendung zu integrieren und deren Potenzial in einem kreativen 
Projekt auszuloten. Während der COVID-19 - Pandemie entstanden zahlreiche Do-it-yourself-Projekte im 
Bereich der Automatisierung, welche uns zu dieser Idee inspirierten.

\subsection{Zielsetzung}
Das Hauptziel des Projekts war die Entwicklung eines skalierbaren Prototyps, der die 
Cocktailzubereitung durch Automatisierung weitgehend vereinfacht. Die Bedienung des Automaten 
sollte intuitiv und nutzerfreundlich sein, sodass Benutzer per Smartphone-App mit wenigen Klicks 
einen Cocktail 'auf Knopfdruck' zubereiten können. Um eine hohe Flexibilität und Erweiterbarkeit 
zu gewährleisten, wurde eine Cloud - basierte Architektur gewählt, die es ermöglicht, mehrere 
Automaten gleichzeitig zu steuern oder eine Maschine mehreren Benutzern zugänglich zu machen. 

Ein weiterer Aspekt des Projekts war der Fokus auf Kosteneffizienz: Ziel war es, eine Lösung zu 
entwickeln, die im Vergleich zu bestehenden kommerziellen Produkten kostengünstiger ist, ohne dabei 
an Funktionalität und Skalierbarkeit einzubüßen.

\subsection{Relevanz}
Das Projekt verbindet aktuelle Trends im Bereich der Smart-Home-Technologien mit praxisorientierten 
Anwendungen des Internet of Things (IoT). Insbesondere die Integration von Cloud-Diensten und 
mobilen Applikationen in eine physische Maschine bietet ein breites Anwendungsfeld für ähnliche 
Automatisierungslösungen, die über den Cocktailautomaten hinausgehen. Durch den Prototyp wird 
gezeigt, wie IoT-Technologien genutzt werden können, um alltägliche Prozesse effizienter zu 
gestalten. 

Darüber hinaus stellt das Projekt eine wertvolle Gelegenheit dar, sich mit modernen Cloud-
Technologien wie Google Cloud Run und Cloud SQL sowie mit der Entwicklung mobiler Anwendungen und 
hardwarebezogener Softwarelösungen auseinanderzusetzen. Dies spiegelt die zunehmende Relevanz 
solcher Technologien in der Industrie wider.

\subsection{Überblick über die Arbeit}
Die vorliegende Projektarbeit gliedert sich wie folgt: Zunächst wird der technologische Hintergrund 
des Projekts vorgestellt, inklusive einer Einführung in IoT und Smart-Home-Systeme sowie der 
verwendeten Technologien. Anschließend werden die Anforderungen und das Konzept des Cocktail-
Automaten dargelegt. Die darauf folgenden Kapitel widmen sich der Umsetzung der drei zentralen 
Komponenten des Systems: der Hardware, dem containerisierten Backend sowie der mobilen App. 

Im weiteren Verlauf wird die Integration der Komponenten beschrieben und die durchgeführten Tests 
dokumentiert. Abschließend werden die erzielten Ergebnisse zusammengefasst, eine kritische Bewertung
 vorgenommen und ein Ausblick auf mögliche Weiterentwicklungen gegeben. Herausforderungen wie der 
 Umgang mit neuen Technologien, die Skalierung des Systems sowie der zeitliche Umfang des Projekts 
 werden im Rahmen der Arbeit reflektiert.

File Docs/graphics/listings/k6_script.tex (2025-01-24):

\subsection{k6 Testskript}
\begin{lstlisting}[language=JavaScript]
  import http from 'k6/http';
  import { check, sleep } from 'k6';
  import { Counter } from 'k6/metrics';
  
  export let errorCounter = new Counter('errors');
  
  export const options = {
    stages: [
      { duration: '1m', target: 1 }, // 1 Nutzer
      { duration: '1m', target: 2 }, // 2 Nutzer
      { duration: '1m', target: 4 }, // 4 Nutzer
      { duration: '1m', target: 5 }, // 5 Nutzer
      { duration: '1m', target: 20 }, // 20 Nutzer
    ],
  };
  
  const BASE_URL = 'https://smartender-432708816033.europe-west3.run.app';
  const API_KEY = 'b0ec1aa3-98bd-434d-b6b6-f72b99383859';
  
  function randomString(length) {
    const chars = 'abcdefghijklmnopqrstuvwxyz1234567890';
    let result = '';
    for (let i = 0; i < length; i++) {
      result += chars.charAt(Math.floor(Math.random() * chars.length));
    }
    return result;
  }
  
  function generateMacAddress() {
    const hex = '0123456789ABCDEF';
    let mac = [];
    for (let i = 0; i < 6; i++) {
      mac.push(
        hex.charAt(Math.floor(Math.random() * 16)) + hex.charAt(Math.floor(Math.random() * 16))
      );
    }
    return mac.join(':');
  }
  
  export default function () {
    // 1. Registrierung
    const username = `user_${randomString(8)}`;
    const password = 'Password123!';
    const email = `${username}@example.com`;
  
    let registerRes = http.post(
      `${BASE_URL}/api/auth/register`,
      JSON.stringify({
        username,
        password,
        email,
      }),
      {
        headers: { 'Content-Type': 'application/json', 'X-API-Key': API_KEY },
      }
    );
  
    check(registerRes, { 'User registration successful': (res) => res.status === 201 });
    if (registerRes.status !== 201) return;
  
    // 2. Login
    let loginRes = http.post(
      `${BASE_URL}/api/auth/login`,
      JSON.stringify({
        username,
        password,
      }),
      {
        headers: { 'Content-Type': 'application/json', 'X-API-Key': API_KEY },
      }
    );
  
    check(loginRes, { 'User login successful': (res) => res.status === 200 });
    if (loginRes.status !== 200) return;
  
    const loginData = JSON.parse(loginRes.body);
    const jwt = loginData.token;
    const userId = parseInt(loginData.userID);
  
    // 3. Hardware registrieren
    //
    let hardwareRes = http.post(
      `${BASE_URL}/smartender/register`,
      JSON.stringify({
        hardware_name: `Hardware_${randomString(5)}`,
        mac_address: generateMacAddress(),
        user_id: userId,
      }),
      {
        headers: {
          'X-API-Key': API_KEY,
          Authorization: `Bearer ${jwt}`,
        },
      }
    );
  
    check(hardwareRes, { 'Hardware registration successful': (res) => res.status === 200 });
    const hardwareData = JSON.parse(hardwareRes.body);
    const hardwareId = hardwareData.hardwareID;
  
    // 4. Drinks anlegen
    let drinks = [];
    for (let i = 0; i < 10; i++) {
      let drinkRes = http.post(
        `${BASE_URL}/api/user/hardware/${hardwareId}/drinks`,
        JSON.stringify({
          drink_name: `Drink_${randomString(5)}`,
          is_alcoholic: Math.random() > 0.5,
        }),
        {
          headers: {
            'Content-Type': 'application/json',
            'X-API-Key': API_KEY,
            Authorization: `Bearer ${jwt}`,
          },
        }
      );
  
      check(drinkRes, { 'Drink creation successful': (res) => res.status === 201 });
      if (drinkRes.status === 201) drinks.push(JSON.parse(drinkRes.body));
    }
  
    // 5. Slots befuellen
    for (let i = 0; i < Math.min(drinks.length, 5); i++) {
      let setSlotRes = http.put(
        `${BASE_URL}/api/user/hardware/${hardwareId}/slots/${i + 1}`,
        JSON.stringify({
          drink_id: drinks[i].drink_id,
        }),
        {
          headers: {
            'Content-Type': 'application/json',
            'X-API-Key': API_KEY,
            Authorization: `Bearer ${jwt}`,
          },
        }
      );
  
      check(setSlotRes, { 'Slot set successfully': (res) => res.status === 204 });
    }
  
    // 6. Rezepte anlegen
    let recipes = [];
    for (let i = 0; i < 10; i++) {
      let recipeRes = http.post(
        `${BASE_URL}/api/user/hardware/${hardwareId}/recipes`,
        JSON.stringify({
          recipe_name: `Recipe_${randomString(5)}`,
          picture_id: Math.floor(Math.random() * 100),
        }),
        {
          headers: {
            'Content-Type': 'application/json',
            'X-API-Key': API_KEY,
            Authorization: `Bearer ${jwt}`,
          },
        }
      );
  
      check(recipeRes, { 'Recipe creation successful': (res) => res.status === 201 });
      if (recipeRes.status === 201) recipes.push(JSON.parse(recipeRes.body));
    }
  
    // 7. Zutaten zu Rezepten hinzufuegen
    for (let i = 0; i < recipes.length; i++) {
      // Fuege jedem Rezept bis zu 3 Zutaten hinzu, falls genuegend Drinks vorhanden sind
      for (let j = 0; j < Math.min(3, drinks.length); j++) {
        let addIngredientRes = http.post(
          `${BASE_URL}/api/user/hardware/${hardwareId}/recipes/${recipes[i].recipe_id}/ingredients`,
          JSON.stringify({
            drink_id: drinks[j].drink_id,
            quantity_ml: Math.floor(Math.random() * 100) + 50, // Zufllige Menge zwischen 50 und 150 ml
          }),
          {
            headers: {
              'Content-Type': 'application/json',
              'X-API-Key': API_KEY,
              Authorization: `Bearer ${jwt}`,
            },
          }
        );
  
        check(addIngredientRes, {
          'Ingredient added successfully': (res) => res.status === 201,
        });
        if (addIngredientRes.status !== 201) {
          errorCounter.add(1);
          console.error(
            `Failed to add ingredient to recipe ${recipes[i].recipe_id}:`,
            addIngredientRes.body
          );
        }
      }
    }
  
    // 8. Favoriten erstellen
    for (let i = 0; i < Math.min(recipes.length, 3); i++) {
      let favoriteRes = http.post(
        `${BASE_URL}/api/user/hardware/${hardwareId}/favorite/${recipes[i].recipe_id}`,
        {},
        {
          headers: {
            'Content-Type': 'application/json',
            'X-API-Key': API_KEY,
            Authorization: `Bearer ${jwt}`,
          },
        }
      );
  
      check(favoriteRes, { 'Favorite created successfully': (res) => res.status === 201 });
    }
  
    // 9. Slots abrufen
    let getSlotsRes = http.get(`${BASE_URL}/api/user/hardware/${hardwareId}/slots`, {
      headers: {
        'X-API-Key': API_KEY,
        Authorization: `Bearer ${jwt}`,
      },
    });
  
    let slots = JSON.parse(getSlotsRes.body);
  
    check(getSlotsRes, { 'Get slots returned an array': () => Array.isArray(slots) });
  
    // 10. Favoriten abrufen
    let getFavoritesRes = http.get(`${BASE_URL}/api/user/hardware/${hardwareId}/favorites`, {
      headers: { 'X-API-Key': API_KEY, Authorization: `Bearer ${jwt}` },
    });
    let favorites = JSON.parse(getFavoritesRes.body);
    check(getFavoritesRes, { 'Get favorites returned an array': () => Array.isArray(favorites) });
  
    // Pause zwischen den Aktionen
    sleep(1);
  }
  
\end{lstlisting}

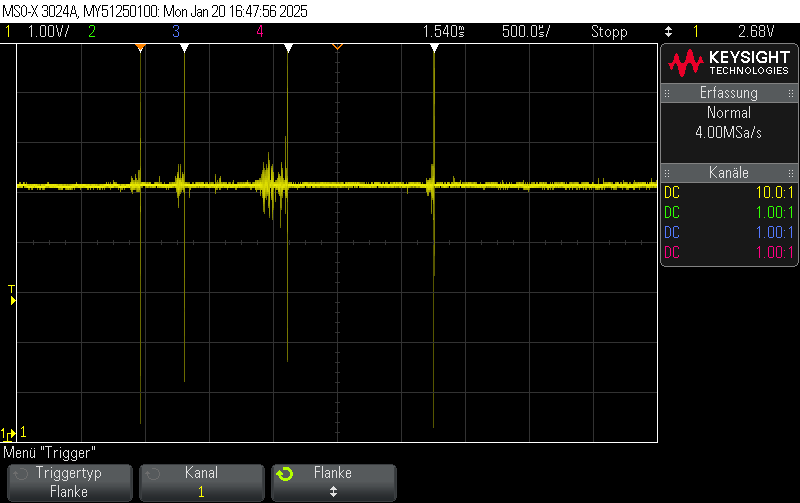
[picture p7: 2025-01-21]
Docs/graphics/images/oszi.png

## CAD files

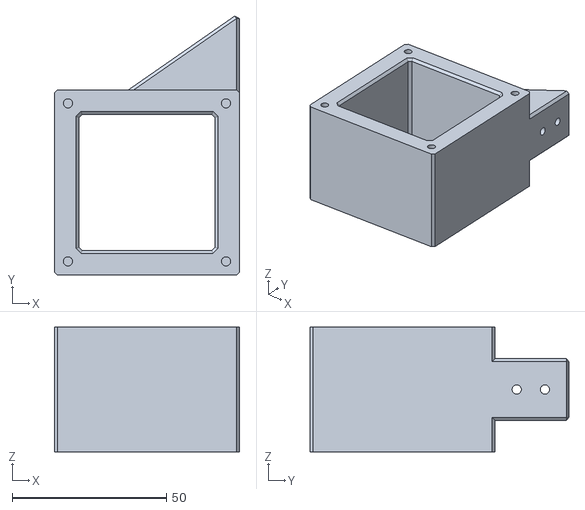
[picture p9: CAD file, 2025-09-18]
CAD-Files/01_stepper_motor/02_stepper_motor_body.stl
60.0 x 83.9 x 40.4

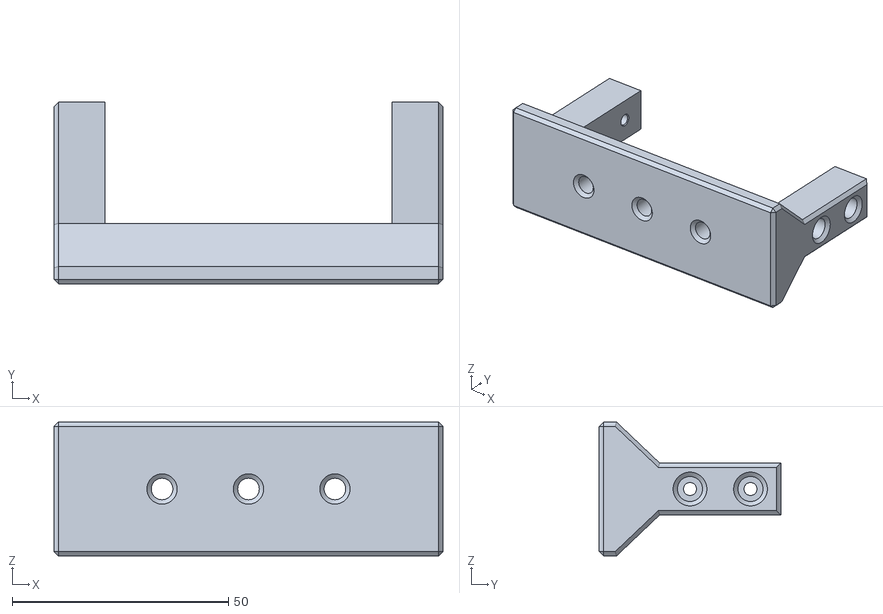
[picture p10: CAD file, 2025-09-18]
CAD-Files/02_gantry_rails/01_ganrtry_back_plate.stl
90.0 x 42.0 x 31.0

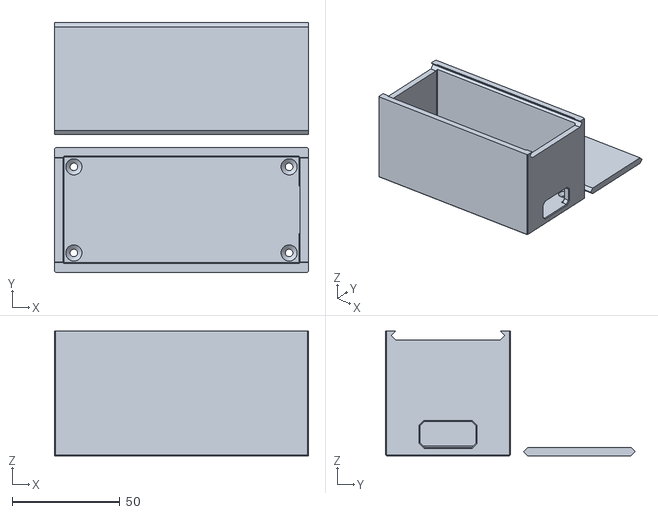
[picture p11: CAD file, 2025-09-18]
CAD-Files/03_relay_box/smartender_v2_20mm.stl
118.0 x 116.0 x 58.0

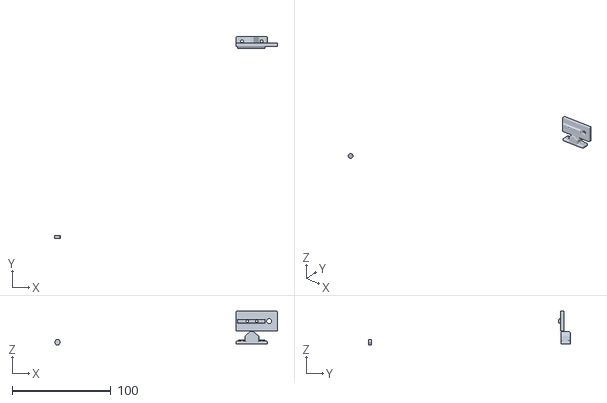
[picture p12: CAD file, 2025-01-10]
CAD-Files/04_micro_switches/01_Micro_switcches.stl
226.0 x 205.0 x 34.0

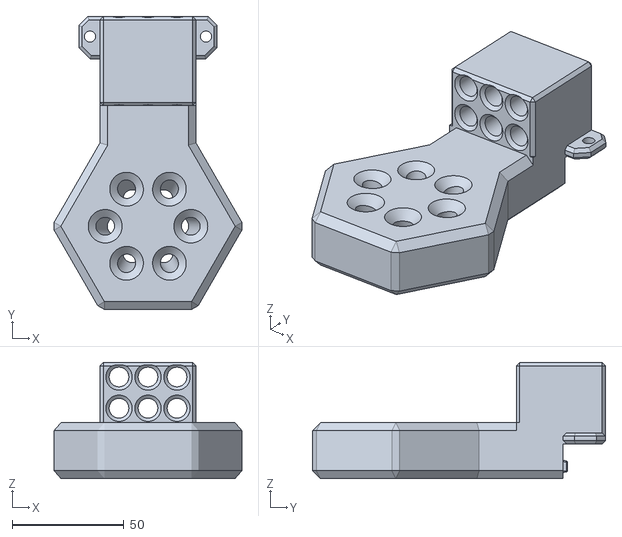
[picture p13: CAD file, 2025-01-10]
CAD-Files/05_tube_holder/01_tube_holder.stl
84.2 x 131.3 x 52.0

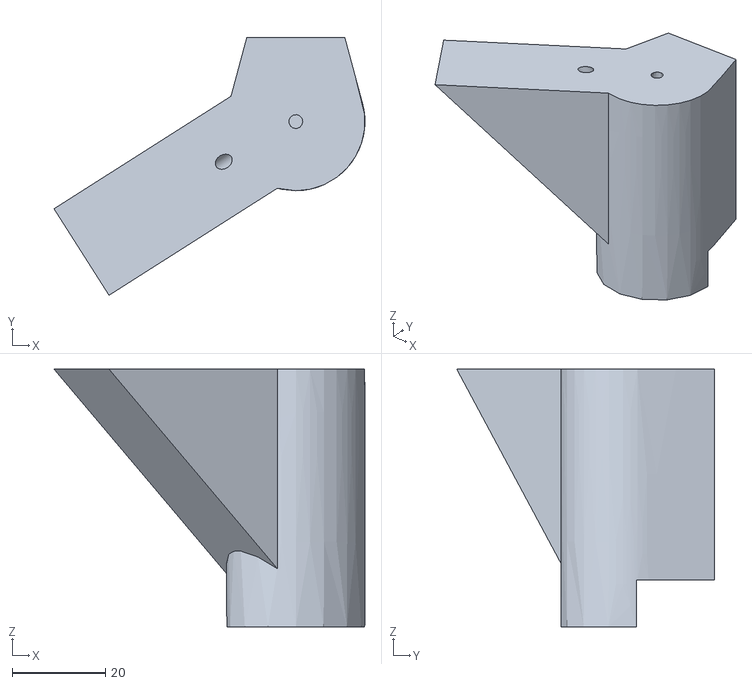
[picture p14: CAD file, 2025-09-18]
CAD-Files/06_linar_servo/02_liear_servo_shaft.stl
66.7 x 55.3 x 55.3

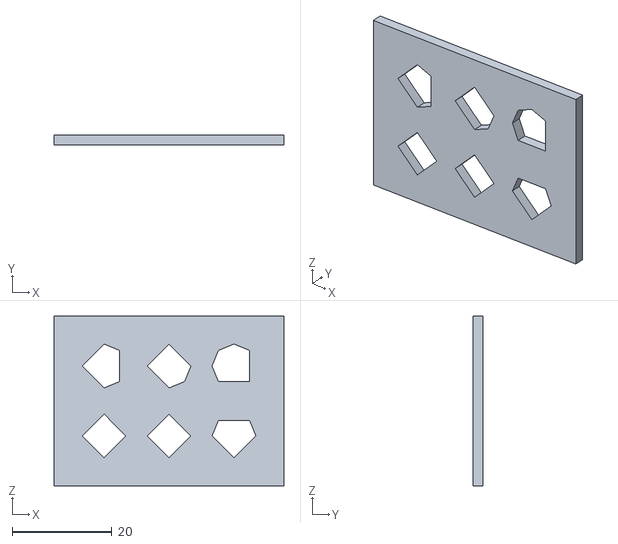
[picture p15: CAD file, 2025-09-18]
CAD-Files/07_pipe_outlet/01_pip_drill_template.stl
46.0 x 2.00 x 34.0

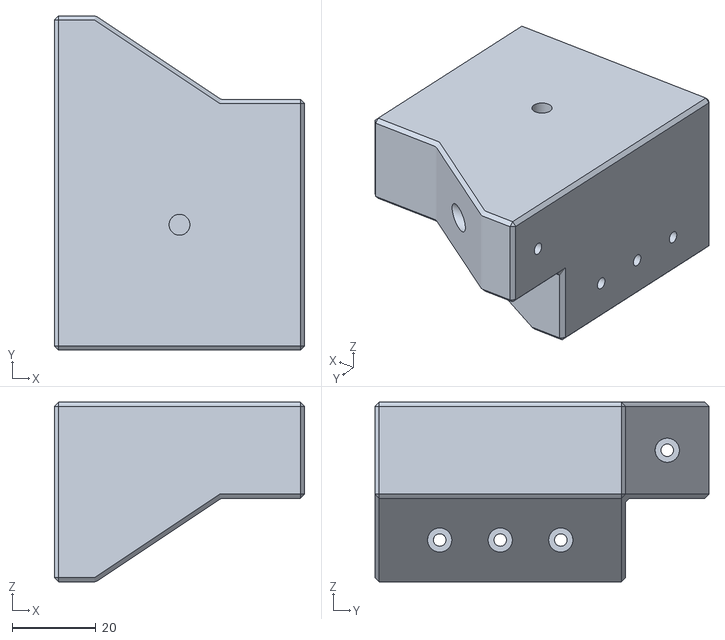
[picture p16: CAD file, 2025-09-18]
CAD-Files/01_stepper_motor/04_stepper_opposing_side.stl
60.0 x 80.0 x 43.0

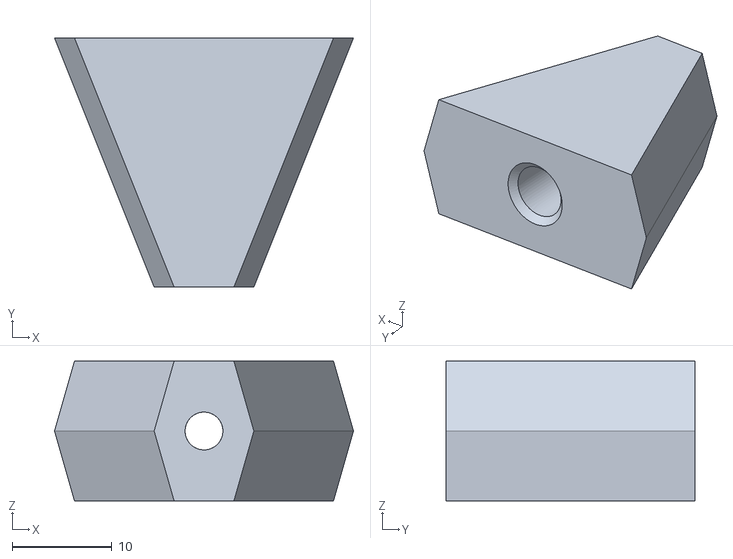
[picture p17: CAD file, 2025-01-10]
CAD-Files/02_gantry_rails/01_ganrtry_back_bell_plug.stl
30.0 x 25.0 x 14.0

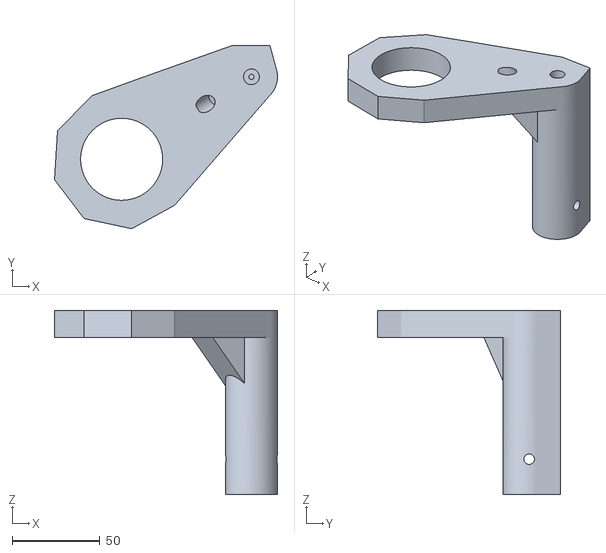
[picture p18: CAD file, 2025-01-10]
CAD-Files/06_linar_servo/01_liear_servo.stl
127.1 x 104.6 x 105.0

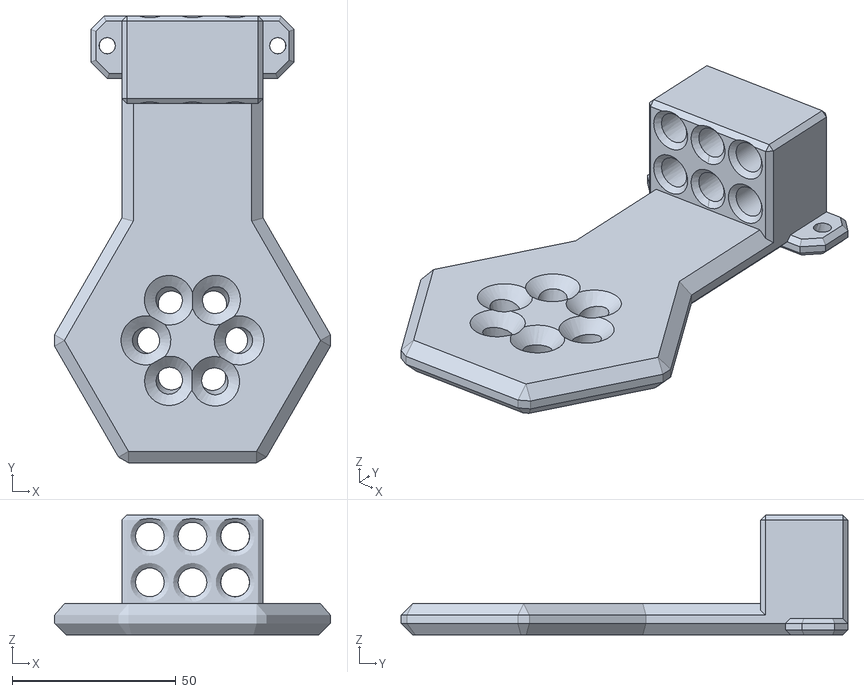
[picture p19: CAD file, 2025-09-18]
CAD-Files/07_pipe_outlet/01_pip_outlet.stl
84.2 x 136.2 x 36.5

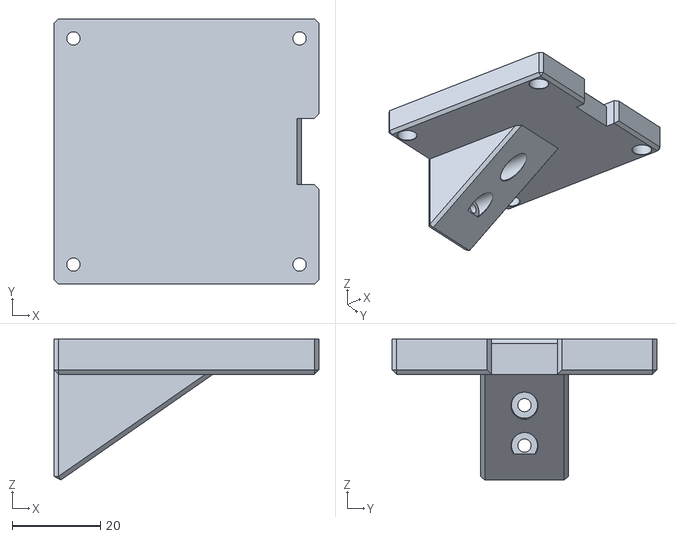
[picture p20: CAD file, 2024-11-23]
CAD-Files/01_stepper_motor/03_stepper_motor_bottom.stl
60.0 x 60.0 x 31.9

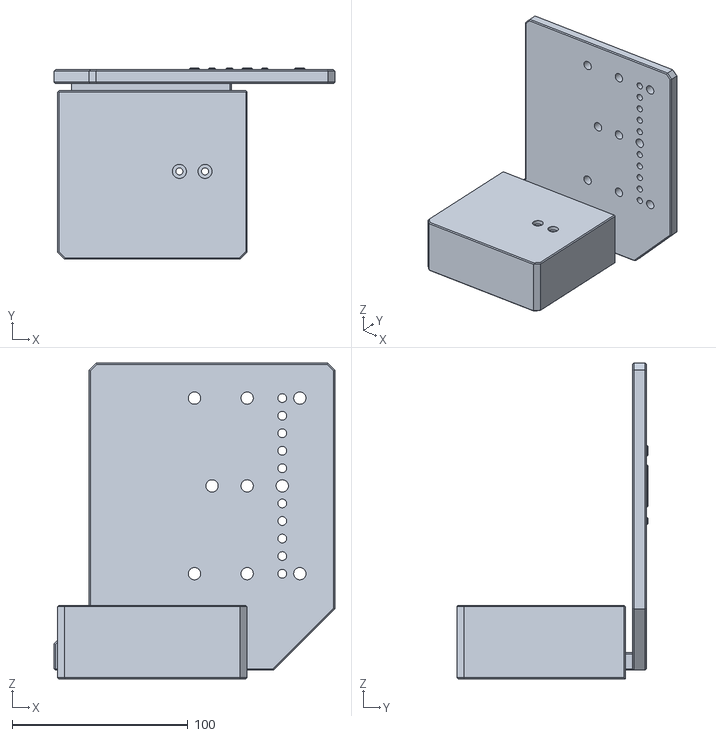
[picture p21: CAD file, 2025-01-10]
CAD-Files/02_gantry_rails/04_ganrtry_front_plate.stl
160.0 x 109.0 x 180.0

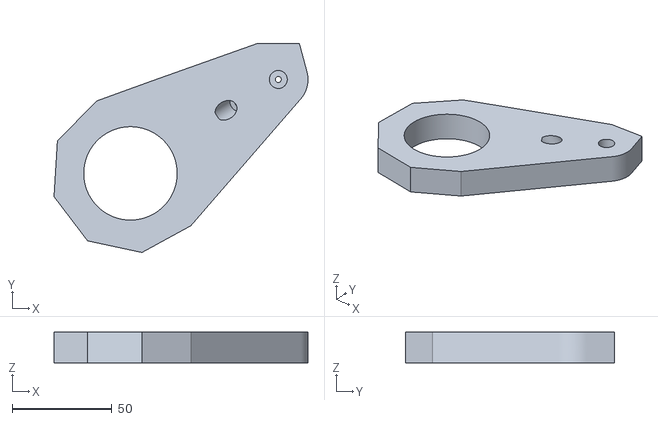
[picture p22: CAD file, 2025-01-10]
CAD-Files/06_linar_servo/01_linear_servo_top.stl
127.1 x 104.6 x 15.5

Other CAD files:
CAD-Files/01_stepper_motor/01_stepper_motor_body.stl
CAD-Files/02_gantry_rails/01_ganrtry_back_bell_grip.stl
CAD-Files/06_linar_servo/03_linear_servo_top.stl
CAD-Files/06_linar_servo/01_liear_servo_adapter_02.stl
CAD-Files/06_linar_servo/01_liear_servo.3dm
CAD-Files/06_linar_servo/01_liear_servo_adapter_04.stl
CAD-Files/06_linar_servo/01_liear_servo_adapter_06.stl
CAD-Files/07_pipe_outlet/01_pip_outlet.3dm

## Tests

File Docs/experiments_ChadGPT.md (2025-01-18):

# Vorgeschlagene Experimente

1. Durchflussrate der Pumpen

   - Experiment: Messt die Durchflussrate (ml/s) der Pumpen bei unterschiedlichen Füllständen der Flüssigkeitsbehälter und verschiedenen Flüssigkeitsviskositäten (z. B. Wasser, Sirup, Saft).
   - Ziel: Bewertung der Präzision bei der Dosierung der Zutaten.
   - Parameter: Füllstand, Viskosität, Pumpleistung.
   - Erwartetes Ergebnis: Eine konstante Durchflussrate unabhängig von den Flüssigkeitseigenschaften.

2. Genauigkeit der Dosierung

   - Experiment: Misst die Differenz zwischen der angeforderten Menge (z. B. 50 ml) und der tatsächlich ausgegebenen Menge.
   - Ziel: Sicherstellen, dass der Cocktailautomat präzise arbeitet.
   - Testfälle: Kleine Mengen (10 ml), mittlere Mengen (50 ml), große Mengen (150 ml).
   - Erwartetes Ergebnis: Abweichung von weniger als 5 %.

3. Konsistenz bei der Mischung

   - Experiment: Prüft, ob die Zusammensetzung der Cocktails (z. B. 40 % Alkohol, 60 % Mixer) bei mehreren Versuchen gleich bleibt.
   - Ziel: Sicherstellung einer konsistenten Qualität.
   - Methode: Analyse der Zutatenanteile mit einer Flüssigkeitswaage.
   - Erwartetes Ergebnis: Gleichmäßige Verteilung bei Wiederholungen.

4. Benutzerfreundlichkeit der App

   - Experiment: Führt einen Usability-Test mit mindestens 5–10 Personen durch, die die App noch nie benutzt haben.
   - Ziel: Identifikation von Problemen bei der Bedienung der App.
   - Metriken: Zeit für die Erstellung eines Rezepts, Fehlerquote, subjektives Benutzerfeedback.
   - Erwartetes Ergebnis: Die Mehrheit bewertet die App als intuitiv und funktional.

5. Netzwerk - und Cloud-Stabilität

   - Experiment: Simuliert Netzwerkausfälle oder eine hohe Serverauslastung, während der Automat Cocktails zubereitet.
   - Ziel: Bewertung der Robustheit des Systems bei schlechten Verbindungen.
   - Parameter: Latenzzeit, Serverauslastung, Offline-Szenarien.
   - Erwartetes Ergebnis: Minimale Verzögerungen und reibungslose Wiederaufnahme der Funktion.

6. Langzeittest der Hardware

   - Experiment: Lässt den Automaten über mehrere Stunden oder Tage eine große Anzahl von Cocktails zubereiten.
   - Ziel: Prüfung auf Überhitzung, Verschleiß oder mechanische Ausfälle.
   - Parameter: Anzahl der Zubereitungen, Betriebszeit, Temperatur der Komponenten.
   - Erwartetes Ergebnis: Keine signifikanten Leistungseinbußen oder Schäden.

7. Energieverbrauch

   - Experiment: Messt den Energieverbrauch des Cocktailautomaten während unterschiedlicher Betriebsmodi (Leerlauf, Zubereitung, Reinigung).
   - Ziel: Optimierung der Energieeffizienz.
   - Parameter: Wattzahl, Laufzeit.
   - Erwartetes Ergebnis: Niedriger Verbrauch im Leerlauf und moderater Verbrauch bei der Zubereitung.

8. Geschmacksblindtest

   - Experiment: Führt einen Blindtest mit verschiedenen Personen durch, um die Qualität der Cocktails zu bewerten.
   - Ziel: Bewertung der Qualität im Vergleich zu manuell gemischten Cocktails.
   - Metriken: Durchschnittliche Bewertung auf einer Skala von 1 bis 10.
   - Erwartetes Ergebnis: Gleichwertige oder bessere Bewertungen im Vergleich zu handgemachten Cocktails.

9. Reinigungsprozess

   - Experiment: Überprüft, wie effektiv der automatische Reinigungsmodus funktioniert, indem Rückstände in Schläuchen oder Behältern gemessen werden.
   - Ziel: Sicherstellung der Hygiene und einfacher Wartung.
   - Methode: Analyse von Rückständen mit Wasserindikator oder pH-Messung.
   - Erwartetes Ergebnis: Keine signifikanten Rückstände nach dem Reinigungsprozess.

10. Kosten-Nutzen-Analyse

    - Experiment: Stellt eine Liste der verwendeten Komponenten und deren Kosten auf und berechnet die Produktionskosten eines Cocktails.
    - Ziel: Evaluierung der Wirtschaftlichkeit.
    - Parameter: Materialkosten, Energieverbrauch, Preis pro Cocktail.
    - Erwartetes Ergebnis: Angemessene Kosten pro Cocktail im Vergleich zu einer Bar.

Falls spezifische Bereiche tiefer getestet werden sollen (z. B. Backend   -Architektur oder App-Sicherheit), könnt ihr weitere detaillierte Tests planen. Gebt Bescheid, falls ihr Hilfe bei der Formulierung oder Umsetzung der Tests benötigt!

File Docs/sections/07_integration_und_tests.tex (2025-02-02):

Die Integration und Tests spielten eine zentrale Rolle im Entwicklungsprozess des Projekts, um 
sicherzustellen, dass die einzelnen Komponenten (App, Backend und Hardware) nahtlos 
zusammenarbeiten und die gesamte Funktionalität des Cocktailautomaten zuverlässig bereitstellen.

\subsection{Integration der Komponenten}

Die Integration des Gesamtsystems wurde schrittweise durchgeführt. Der Fokus lag darauf, die 
Kommunikation zwischen der App, dem Backend und der Hardware zu überprüfen und sicherzustellen, 
dass Bestellungen korrekt verarbeitet und an die Hardware weitergeleitet werden. Im Rahmen des 
Projekts wurde dabei folgender Prozess verifiziert:

\begin{itemize}
  \item Die mobile App sendet eine Bestellung mit einem Rezept an das Backend.
  \item Das Backend verarbeitet die Bestellung, greift auf die Rezeptdatenbank zu und leitet die 
relevanten Steuerbefehle an die Hardware weiter.
  \item Die Hardware führt die Befehle aus, steuert die Pumpen und Motoren an und stellt das 
gewünschte Rezept her.
\end{itemize}
Die Integrationsprüfung umfasste dabei verschiedene Szenarien, einschließlich der Erstellung und 
Zubereitung mehrerer Testrezepte, wobei aus praktischen Gründen Wasser anstelle der tatsächlichen 
Zutaten verwendet wurde. Die erfolgreiche Durchführung dieser Tests zeigte, dass die gesamte 
Prozesskette von der App bis zur Hardware stabil und fehlerfrei funktioniert.

\subsection{Teststrategie}

Im Projekt wurden die Tests ad hoc und iterativ durchgeführt, um Fehler schnell zu identifizieren 
und zu beheben. Die wichtigsten Tests waren:

\hyphenation{Funk-tio-na-li-tät}
% TODO: fix overfull hbox in 'App-Usability-Tests'
\begin{itemize}
  \item \textbf{Integrationstests:} Regelmäßige Überprüfung, ob die gesamte Prozesskette 
    (App \textrightarrow{} Backend \textrightarrow{} Hardware) wie gewünscht funktioniert.
  \item \textbf{Systemtests:} Abschließende Tests, bei denen mehrere Testrezepte angelegt und 
    zubereitet wurden. Diese Tests stellten sicher, dass die Datenübertragung, Rezeptverwaltung und 
    Hardwaresteuerung korrekt umgesetzt sind.
  \item \textbf{Lasttests:} Überprüfung der Systemperformance und Stabilität bei höherer Belastung 
    (siehe Abschnitt \ref{subsec:lasttests}).
  \item \textbf{App-Usability-Tests:} Um die Benutzerfreundlichkeit und Funktionalität der mobilen 
    App zu evaluieren, wurde diese neun Personen vorgestellt. Die Nutzer erhielten die Gelegenheit, 
    alle Funktionen der App zu testen. Anschließend bewerteten sie die App in den Kategorien 
    \textit{Benutzerfreundlichkeit}, \textit{Funktionsumfang} sowie \textit{Stabilität und Leistung} 
    auf einer Skala von 1 (schlecht) bis 5 (sehr gut). Die Ergebnisse waren überwiegend positiv, 
    insbesondere im Bereich Stabilität und Leistung, wo keine Probleme festgestellt wurden. Alle 
    Teilnehmer lobten die intuitive Bedienung und das klare Design.
  \item \textbf{Pumpleistungstest:} Überprüfung der Funktionalität und Genauigkeit der Pumpsysteme. 
    Dabei wurden die Pumpen mit Wasser befüllt und die ausgegebene Menge mittels einer Waage 
    gemessen.
\end{itemize}

\subsection{Lasttests}
\label{subsec:lasttests}

Um die Skalierbarkeit und Performance des Systems zu überprüfen, wurden Lasttests mithilfe von 
\texttt{k6} durchgeführt. Die Tests konzentrierten sich auf die Belastbarkeit der Backend-API bei 
einer großen Anzahl gleichzeitiger Anfragen. Dabei wurden unterschiedliche Szenarien simuliert, 
darunter das Abrufen von Rezepten und das Auslösen von Bestellungen.\newline

\textbf{Beispiel-Szenario:}
\begin{itemize}
  \item Stufenweise Erhöhung der gleichzeitigen Benutzer von 1 auf 20 in Intervallen von 30 Sekunden.
  \item Messung von Latenzzeiten, Fehlerraten und Erfolgsquoten.
\end{itemize}

\textbf{Herausforderungen:} Während der Tests zeigte sich, dass bei starker Auslastung und 
mehreren Containerinstanzen Bestellungen nicht immer korrekt verarbeitet wurden. Dies lag daran, 
dass Websocket-Verbindungen jeweils im RAM der Container gehalten werden. Wenn eine Anfrage an 
einen anderen Container weitergeleitet wird, als den, der die Verbindung hält, konnte diese nicht 
verarbeitet werden.\newline

% TODO: fix tangling references
\textbf{Ergebnisse:} Die genaue Analyse der Lasttestergebnisse wird in Abschnitt 
\ref{subsec:lasttest_results} beschrieben.

\subsection{Fehlerbehebung und Lösungen}

Ein Hauptproblem während der Lasttests war die Verwaltung der Websocket-Verbindungen. Um dieses 
Problem zu beheben, könnten folgende Maßnahmen zukünftig implementiert werden:

\begin{itemize}
  \item Verwendung eines dedizierten Websocket-Servers, der Verbindungen zentral verwaltet.
  \item Einführung eines Lastverteilers, der Anfragen konsistent an die richtigen Container 
  weiterleitet.
\end{itemize}
Diese Maßnahmen könnten die Zuverlässigkeit und Skalierbarkeit des Systems erheblich verbessern.

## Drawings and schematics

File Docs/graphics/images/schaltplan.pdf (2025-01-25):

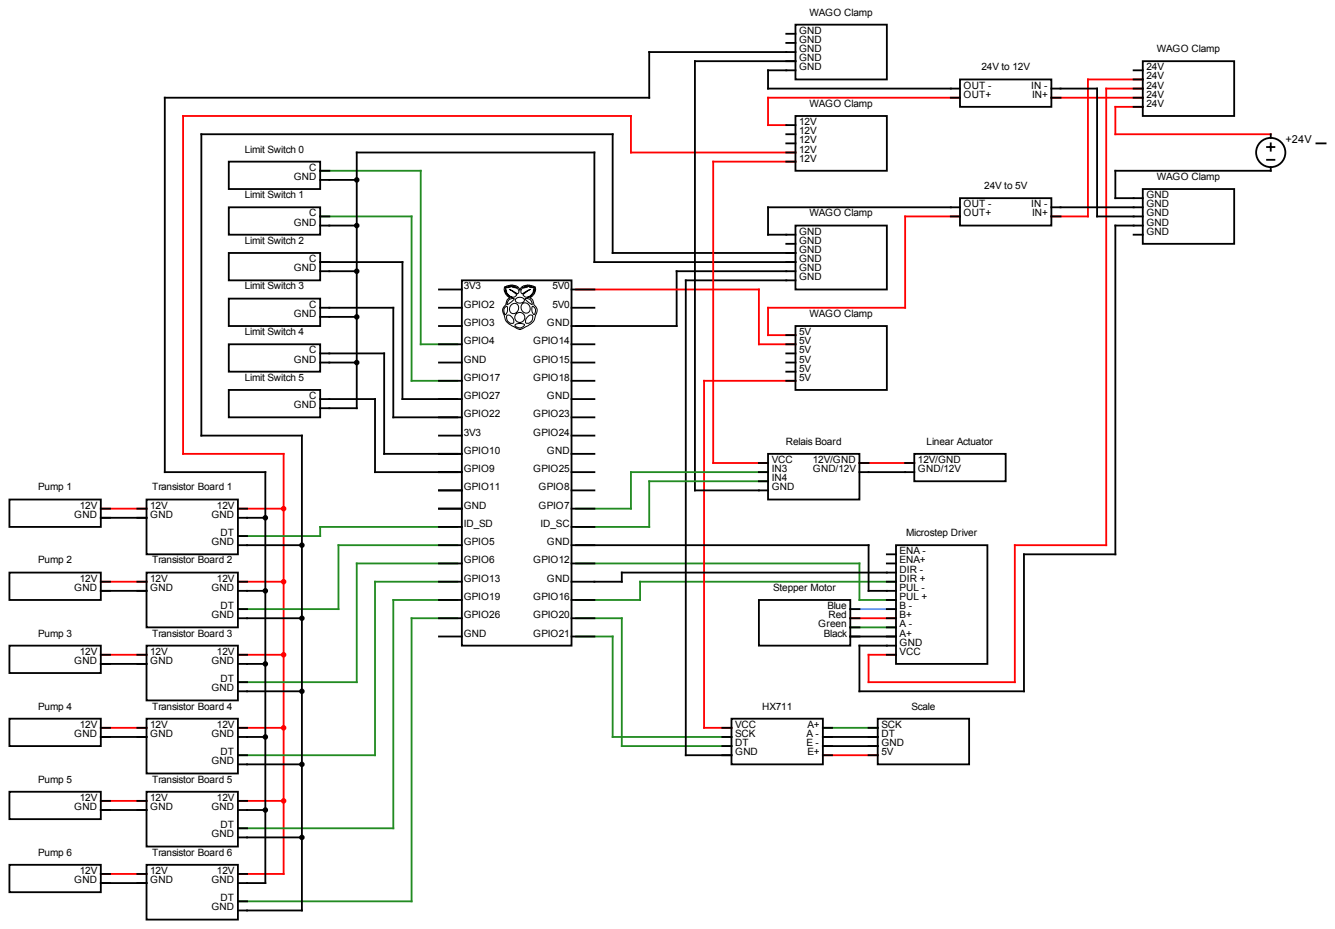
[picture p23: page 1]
Relais Board; VCC; 12V/GND; GND/12V; IN4 GND; Linear Actuator; 12V/GND GND/12V; WAGO Clamp; GND GND GND GND GND; OUT -; OUT+; Transistor Board 6; GND; DT GND; Transistor Board 5; Transistor Board 4; Transistor Board 3; Transistor Board 2; Transistor Board 1; Microstep Driver; ENA - ENA+ DIR - DIR + PUL - PUL + B - B+ A - A+ GND VCC; Stepper Motor; Blue Red Green Black; Scale; SCK DT GND 5V; SCK; Pump 3; 12V GND; Pump 6; Pump 5; Pump 4; Pump 2; Pump 1; Limit Switch 0; C GND; Limit Switch 5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

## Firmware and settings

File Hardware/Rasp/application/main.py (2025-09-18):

from modules.websocket_handler import WebSocketHandler
from modules.command_mapper import CommandMapper
from modules.utils.logger import Logger
from modules.motor_controller import MotorController
from modules.position_handler import PositionHandler
from modules.pump_controller import PumpController
from modules.weight_sensor import WeightSensor
from modules.actuator_controller import ActuatorController
from modules.led_controller import LEDController
# --------------------------------------------------------------------------------------------------
from modules.utils.logger import Logger
from modules.error_handler import ErrorHandler
# --------------------------------------------------------------------------------------------------
from rx import create
from rx.subject import Subject
import time
from dotenv import load_dotenv
import os
import uuid
import math
# --------------------------------------------------------------------------------------------------

def main():
    logger = Logger()
    logger.log("INFO", "Application started", "Main")

    # Initialize WebSocketHandler
    url = "wss://smartender-432708816033.europe-west3.run.app/smartender/socket"
    # Load environment variables from .env file
    load_dotenv()
    
    mac = uuid.getnode()
    mac_address = ':'.join(f'{(mac >> i) & 0xFF:02x}' for i in range(40, -1, -8))
    
    headers = {
        "x-api-key": os.getenv("X_API_KEY"),
        "Hardware-Auth-Key": os.getenv("HARDWARE_AUTH_KEY"),
        "Identifier": mac_address,
    }

    logger.log("INFO", headers, "Main")

    websocket_handler = WebSocketHandler(url, headers)
    # Initialize CommandMapper
    command_mapper = CommandMapper()

    # Initialize Hardware Components
    position_handler = PositionHandler(limit_switch_pins=[4, 17, 27, 22, 10, 9])
    weight_sensor = WeightSensor(dt_pin=20, sck_pin=21)
    motor_controller = MotorController(dir_pin=16, pull_pin=12)
    pump_controller = PumpController(pump_pins=[0, 5, 6, 13, 19, 26], weight_sensor=weight_sensor, position_handler=position_handler)
    actuator_controller = ActuatorController(
        in_pins={"in3": 7, "in4": 1},
        weight_sensor=weight_sensor,
        position_handler=position_handler,
    )
    #led_controller = LEDController(LV1_pin=18)

    # Extract subscriptions to subjects from the hardware components
    motor_controller_subject = motor_controller.subscribe()
    position_handler_subject = position_handler.subscribe()
    pump_controller_subject = pump_controller.subscribe()
    weight_sensor_subject = weight_sensor.subscribe()
    # actuator_controller_subject = actuator_controller.subscribe()

    error_handler = ErrorHandler(websocket_instance=websocket_handler.ws)
    # TODO: pass error_handler to controllers and handlers
    # 
    #  - [ ] command_mapper
    #  - [x] motor_controller
    #  - [x] position_handler
    #  - [x] pump_controller
    #  - [x] weight_sensor
    #  - [x] actuator_controller
    #  - [ ] led_controller

    logger.log("INFO", "Hardware components initialized", "Main")

    # Subscribe to WebSocket messages
    websocket_handler.message_subject.subscribe(
        on_next=lambda message: process_message(
            message, command_mapper, motor_controller, pump_controller, actuator_controller, position_handler, weight_sensor, logger
        ),
        on_error=lambda e: logger.log("ERROR", f"WebSocket stream error: {e}", "Main"),
        on_completed=lambda: logger.log("INFO", "WebSocket stream completed", "Main"),
    )

    # Start WebSocket handler
    websocket_handler.start()
    #actuator_controller._move_down(3)
    #led_controller.progress_bar()
    #time.sleep(2)

    actuator_controller._move_down(1)

    # Move stepper motor to position 0
    if not position_handler.is_home_position():
        motor_controller.rotate_stepper_pigpio(500, 0, 2000)
        motor_controller.rotate_until_limit(0, position_handler, 1, 1000)


    try:
        # Keep the main thread running
        while True:
            pass
    except KeyboardInterrupt:
        logger.log("INFO", "Application is shutting down", "Main")
        websocket_handler.stop()
    finally:
        # Cleanup hardware components
        motor_controller.cleanup()
        position_handler.cleanup()
        pump_controller.cleanup()
        actuator_controller.cleanup()
        #led_controller.cleanup()
        #weight_sensor.cleanup()
        logger.log("INFO", "Hardware components cleaned up", "Main")


def process_message(message, command_mapper, motor_controller, pump_controller, actuator_controller, position_handler, weight_sensor, logger):
    """
    Process a single WebSocket message.

    Args:
        message (str): The WebSocket message received.
        command_mapper (CommandMapper): The CommandMapper instance.
        motor_controller (MotorController): The MotorController instance.
        pump_controller (PumpController): The PumpController instance.
        actuator_controller (ActuatorController): The ActuatorController instance.
        position_handler (PositionHandler): The PositionHandler instance.
        weight_sensor (WeightSensor): The WeightSensor instance.
        logger (Logger): The Logger instance.
    """
    logger.log("INFO", f"Processing message: {message}", "Main")
    commands = command_mapper.map_command(message)

    if commands:
        sorted_commands = sorted(commands, key=lambda item: item.slot_number)

        #motor_controller.rotate_until_limit(1, position_handler, 0, 1000)
        #time.sleep(3)

        #actuator_controller._move_up(2.7)
        #time.sleep(10)
        #actuator_controller._move_down(3.5)
        #led_controller.progress_bar()
        #motor_controller.rotate_stepper_pigpio(4000, 0, 10000)
        #motor_controller.rotate_until_limit(0, position_handler, 1, 1000)
        #pump_controller.activate_pump(0, 4)
        #return 
        #time.sleep(1000)

        logger.log("INFO", f"Commands processed: {sorted_commands}", "Main")
        for command in sorted_commands:
            try:
                # pump_controller.activate_pump(5, 3)  # Placeholder logic
                # Determine if the drink is alcoholic or non-alcoholic
                if 1 <= command.slot_number <= 5:  # Alcoholic
                    logger.log("INFO", f"Alcoholic drink: Slot {command.slot_number}", "Main")

                    # Move to the correct slot with acceleration
                    logger.log("INFO", f"Moving to slot {command.slot_number} with acceleration", "MotorController")

                    # Rotate the stepper motor and stop when the limit switch is pressed
                    motor_controller.rotate_until_limit(command.slot_number, position_handler, 0)
                    logger.log("INFO", f"Moved to slot {command.slot_number}", "MotorController")
                    time.sleep(2)

                    if position_handler.get_position() != command.slot_number:
                        logger.log("ERROR", "Failed to reach the correct slot", "Main")
                        break

                    logger.log("INFO", f"Reached slot {command.slot_number}", "Main")

                    
                    pump_amount = math.ceil(command.quantity_ml/40)          
                    
                    for i in range(pump_amount):
                        # Pour using the actuator
                        logger.log("INFO", f"Pouring from slot {command.slot_number}", "Main")
                        actuator_controller._move_up(2.7)
                        time.sleep(6)
                        actuator_controller._move_down(3)

                elif 6 <= command.slot_number <= 11:  # Non-alcoholic
                    logger.log("INFO", f"Non-alcoholic drink: Slot {command.slot_number}", "Main")

                    # Ensure belt is at the home position (limit switch 0)
                    if position_handler.get_position() != 0:
                        motor_controller.rotate_until_limit(0, position_handler, 1, 1000)

                    if position_handler.get_position() != 0:
                        logger.log("ERROR", "Failed to return to home position", "Main")
                        break

                    time.sleep(0.5)
                    # Pump the drink
                    pump_index = command.slot_number - 6
                    logger.log("INFO", f"Activating pump {pump_index}", "Main")
                    actuator_controller._move_up(5)
                    pump_controller.activate_pump(pump_index, command.quantity_ml/32.5)
                    actuator_controller._move_down(6)
                else:
                    logger.log("ERROR", "Invalid slot number", "Main")
                    break

                # # Check weight sensor for errors
                # current_weight = weight_sensor.read_weight()
                # logger.log("INFO", f"Current weight: {current_weight} g", "Main")
                
                # if current_weight > 395:
                #     logger.log("ERROR", "Weight to high, potential physical Overflow", "Main")
                #     break


            except Exception as e:
                logger.log("ERROR", f"Error processing command: {e}", "Main")
        if position_handler.get_position() != 0:
            logger.log("INFO", "Moving to slot 0", "Main")
            motor_controller.rotate_stepper_pigpio(500, 0, 2000)
            motor_controller.rotate_until_limit(0, position_handler, 1)
    else:
        logger.log("ERROR", "No Commands received", "Main")


if __name__ == "__main__":
    main()

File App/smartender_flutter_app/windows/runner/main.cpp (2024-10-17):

#include <flutter/dart_project.h>
#include <flutter/flutter_view_controller.h>
#include <windows.h>

#include "flutter_window.h"
#include "utils.h"

int APIENTRY wWinMain(_In_ HINSTANCE instance, _In_opt_ HINSTANCE prev,
                      _In_ wchar_t *command_line, _In_ int show_command) {
  // Attach to console when present (e.g., 'flutter run') or create a
  // new console when running with a debugger.
  if (!::AttachConsole(ATTACH_PARENT_PROCESS) && ::IsDebuggerPresent()) {
    CreateAndAttachConsole();
  }

  // Initialize COM, so that it is available for use in the library and/or
  // plugins.
  ::CoInitializeEx(nullptr, COINIT_APARTMENTTHREADED);

  flutter::DartProject project(L"data");

  std::vector<std::string> command_line_arguments =
      GetCommandLineArguments();

  project.set_dart_entrypoint_arguments(std::move(command_line_arguments));

  FlutterWindow window(project);
  Win32Window::Point origin(10, 10);
  Win32Window::Size size(1280, 720);
  if (!window.Create(L"smartender_flutter_app", origin, size)) {
    return EXIT_FAILURE;
  }
  window.SetQuitOnClose(true);

  ::MSG msg;
  while (::GetMessage(&msg, nullptr, 0, 0)) {
    ::TranslateMessage(&msg);
    ::DispatchMessage(&msg);
  }

  ::CoUninitialize();
  return EXIT_SUCCESS;
}

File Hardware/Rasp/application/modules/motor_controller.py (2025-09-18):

import RPi.GPIO as GPIO
import time
from modules.utils.logger import Logger
from modules.error_handler import ErrorHandler
from rx import create
from rx.subject import Subject
import pigpio

class MotorController:
    def __init__(self, dir_pin=16, pull_pin=12, error_handler=None):
        """
        Initialize the stepper motor controller.
        :param dir_pin: GPIO pin for direction control.
        :param pull_pin: GPIO pin for pulsing steps.
        """
        self.logger = Logger()
        self.message_subject = Subject()
        self.dir_pin = dir_pin
        self.pull_pin = pull_pin

        self.pi = pigpio.pi()
        self.pi.set_mode(self.pull_pin, pigpio.OUTPUT)
        self.pi.set_mode(self.dir_pin, pigpio.OUTPUT)

    def subscribe(self):
        """
        Subscribe to limit switch events.
        :return: Subscription object.
        """
        return self.message_subject.subscribe()


    def rotate_stepper_pigpio(self, steps, direction, frequency):
            self.pi.write(self.dir_pin, direction)
            self.pi.hardware_PWM(self.pull_pin, frequency, 500000)  # 50% duty cycle
            time.sleep(steps / frequency)
            self.pi.hardware_PWM(self.pull_pin, 0, 0)  # Stop PWM

    def rotate_until_limit(self, target_slot, position_handler, direction, frequency=2000):
        """
        Rotate the stepper motor until the specified limit switch is triggered.
        :param target_slot: The target slot number (limit switch index).
        :param position_handler: PositionHandler instance for limit switch states.
        :param frequency: Frequency of the pulse signal in Hz.
        :param direction: Direction (1 for clockwise, 0 for counterclockwise).
        """
        self.pi.write(self.dir_pin, direction)
        self.pi.hardware_PWM(self.pull_pin, frequency, 500000)  # 50% duty cycle

        try:
            while position_handler.get_position() != target_slot:
                time.sleep(0.0001)  # Check the limit switch state periodically
        finally:
            self.pi.hardware_PWM(self.pull_pin, 0, 0)  # Stop PWM once the limit switch is pressed
            self.logger.log("INFO", f"Limit switch {target_slot} triggered. Motor stopped.", "MotorController")


    def cleanup(self):
        """Stop all signals and close the pigpio connection."""
        self.pi.hardware_PWM(self.pull_pin, 0, 0)  # Stop PWM on the PUL pin
        self.pi.stop()  # Disconnect from pigpio daemon

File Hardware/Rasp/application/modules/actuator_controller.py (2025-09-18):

import RPi.GPIO as GPIO
import time
from modules.utils.logger import Logger
from rx import create
from rx.subject import Subject

class ActuatorController:
    def __init__(self, in_pins, weight_sensor, position_handler):
        """
        Initialize the actuator controller.
        :param in_pins: Dictionary with keys 'in3' and 'in4' for actuator control pins.
        :param weight_sensor: Weight sensor instance.
        :param position_handler: Position handler instance.
        """
        self.logger = Logger()
        self.message_subject = Subject()
        self.weight_sensor = weight_sensor
        self.position_handler = position_handler
        self.in3 = in_pins["in3"]
        self.in4 = in_pins["in4"]

        GPIO.setmode(GPIO.BCM)
        GPIO.setup(self.in3, GPIO.OUT)
        GPIO.setup(self.in4, GPIO.OUT)
        GPIO.output(self.in3, GPIO.LOW)
        GPIO.output(self.in4, GPIO.LOW)

    def activate(self, amount: int):
        """
        Activate the actuator to pour a specific amount.
        :param amount: Target weight of liquid to pour (grams).
        """
        if self.position_handler.current_position is None:
            self.logger.log("ERROR", "Actuator can only be activated in valid positions", "ActuatorController")
            raise ValueError("Actuator can only be activated in valid positions")

        weight_before_pour = self.weight_sensor.get_weight()

        self._move_up()
        while self.weight_sensor.get_weight() - weight_before_pour < amount:
            # Emergency stop on overflow
            if self.weight_sensor.get_weight() > 400:
                self._emergency_stop()
                self.logger.log("ERROR", "Weight sensor detected liquid overflow", "ActuatorController")
                break

        self._move_down()

    def _move_up(self, duration):
        """Move the actuator down."""
        GPIO.output(self.in3, GPIO.LOW)
        GPIO.output(self.in4, GPIO.HIGH)
        time.sleep(duration)  # Duration for moving down (adjust as needed)
        GPIO.output(self.in4, GPIO.LOW)
        self.logger.log("INFO", "Actuator moving up", "ActuatorController")

    def _move_down(self, duration):
        """Move the actuator up."""
        GPIO.output(self.in3, GPIO.HIGH)
        GPIO.output(self.in4, GPIO.LOW)
        self.logger.log("INFO", "Actuator moving down", "ActuatorController")
        time.sleep(duration)
        GPIO.output(self.in3, GPIO.LOW)

    def _emergency_stop(self):
        """Stop the actuator in an emergency."""
        GPIO.output(self.in3, GPIO.LOW)
        GPIO.output(self.in4, GPIO.LOW)
        self.logger.log("ALERT", "Actuator emergency stop triggered", "ActuatorController")

    def cleanup(self):
        """Clean up GPIO settings."""
        GPIO.cleanup([self.in3, self.in4])
        self.logger.log("INFO", "GPIO cleanup complete for actuator", "ActuatorController")

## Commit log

2024-10-17 Frontend: Login und JWT Implementiert
2024-10-25 ausversehen in dev gearbeitet
2024-10-27 [BUGFIX] Keypad oeffnet sich bei bei username und email wieder
2024-11-02 feat(backend): :construction: minor process on slot endpoints
2024-11-04 fix(backend): :bug: wip: Slot endpoints
2024-11-04 feat(backend): slot endpoints
2024-11-07 Dropdown menu improved and availabe button added
2024-11-23 feat(CAD): created some stl files for the stepper motor
    [01_stepper_motor_body.stl, 02_stepper_motor_body.stl, 03_stepper_motor_bottom.stl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]
2024-11-23 feat(backend): sql query for recipe and socket
2024-11-25 fix(backend): small fix, that only slots of hardware, that you own, can be changed
2024-12-07 feat(CAD): :art: added Relay Box
    [02_stepper_motor_body.stl, 04_stepper_opposing_side.stl, smartender_v2_20mm.stl]
2024-12-07 fix(backend): fixed slot query
2024-12-07 feat(hardware): :tada: Added first sample server in python
2024-12-09 feat(pi): added socket functionality
2024-12-09 theme switch works
2024-12-14 feat(CAD): gantry back
    [01_ganrtry_back_plate.stl]
2024-12-18 morgen gluehwein lecker
2024-12-20 edit pinning
    [pinning.ods]
2025-01-05 bottle slots
2025-01-07 slots overflow behoben
2025-01-10 added new stls
    [01_Micro_switcches.stl, 01_ganrtry_back_bell_grip.stl, 01_ganrtry_back_bell_plug.stl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]
2025-01-10 isAlcohol wird auf DrinkTile angezeigt
2025-01-10 fix(doc): updated pinning
    [pinning.ods]
2025-01-11 feat(hardware): :sparkles: first draft for an error handler class
    [error_handler.py]
2025-01-11 ae ue oe und ss geht
2025-01-11 fix(hardware): :bug: Adjusted Error Codes
    [error_handler.py]
2025-01-12 feat(CAD): :art: Added some more STLs
    [01_pip_drill_template.stl, 01_pip_outlet.3dm, 01_pip_outlet.stl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]
2025-01-17 changes to stepper motor code
2025-01-17 stepper new
2025-01-17 fix(hardware): :sparkles: added proper Hardware-Auth-Key
    [main.py]
2025-01-17 feat(backend): :construction: small changes in ErrorHandler
    [error_handler.py]
2025-01-17 fix(pi): changes to linear actuator
    [actuator_controller.py, main.py]
2025-01-17 rotieren der App deaktiviert
2025-01-18 pinning: changed pinning
    [pinning.ods]
2025-01-20 fix(pi): no leds
2025-01-20 trial and error with leds
    [main.py]
2025-01-21 no leds
2025-01-24 pinning final
    [pinning.ods]
2025-01-25 hardware mit pinning und schaltplan
2025-01-25 als ob der meinen namen falsch schreibt...
2025-02-02 docs(docs): added text to pump boxplot
2025-08-16 Add CAD-Files/ to .gitignore
2025-08-16 Ignore CAD-Files directory
2025-08-21 jetzt wirklich deployed auf die server
2025-08-22 backend fertig und laaaauuuuuffffttttt
